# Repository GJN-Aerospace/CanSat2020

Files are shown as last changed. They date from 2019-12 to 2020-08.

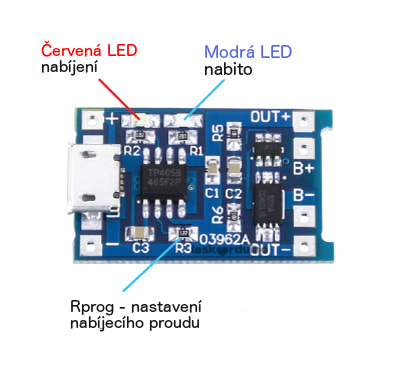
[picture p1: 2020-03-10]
Probe/Hardware/Components/Battery/Nabíječka Li-ion článku TP4056 s ochranou/LA120013-4.png

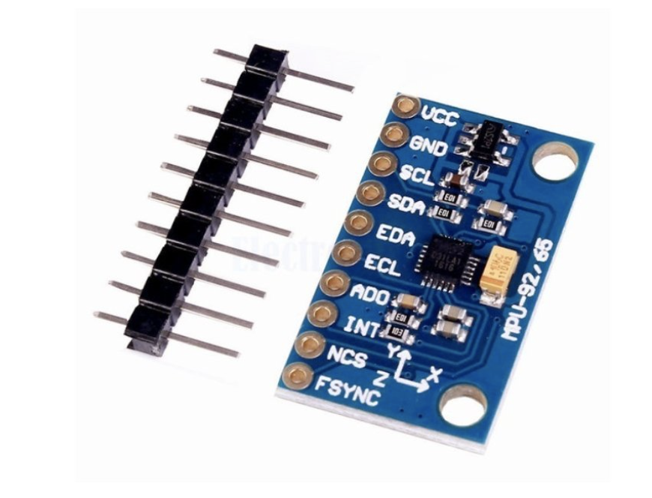
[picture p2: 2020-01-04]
Probe/Hardware/Components/MPU-9250/Screenshot 2020-01-01 at 14.21.48.png

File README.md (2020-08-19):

# CanSat 2020

<a href="https://github.com/GJN-Aerospace">GJN Aerospace Logo</a>

GitHub repository for CanSat 2020 competitoin. You can find here a design of **our CanSat probe PKII** but also our Arduino code for openCanSat kit. 

## Probe

We designed our own probe. It name is "Cosmic Song II" or for short just CSII (in czech Píseň kosmická II, PKII). But we have in Software section a code for our backup probe from openCanSat kit. 

## GroundStation

We use as a our Ground Station a baseStation from openCanSat kit. So you can find in Software folder our code for it. 

### Links

* [openCanSat](http://kit.sciencein.cz)

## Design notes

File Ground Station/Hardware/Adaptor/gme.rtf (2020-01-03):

https://www.gme.cz/redukce-sma-bnc-z-z-50r

Redukce z SMA zásuvka na BNC zásuvka. Impedance 50ohm. Materiál: niklovaná mosaz (NM), izolace: teflon

Kód produktu | 816-044
Váha | 0.00960 Kg
Redukce z: | SMA zásuvka -
Poznámka: | - -
Redukce na: | BNC zásuvka -
Tvar redukce: | Rovná -
Typ: | Redukce -
Výrobce: | - -

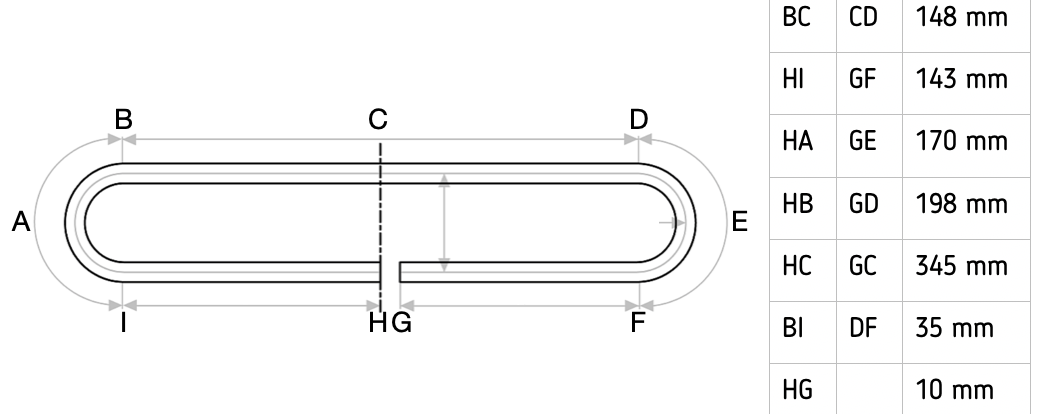
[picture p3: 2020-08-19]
Ground Station/Hardware/Antenna/Dipole.png

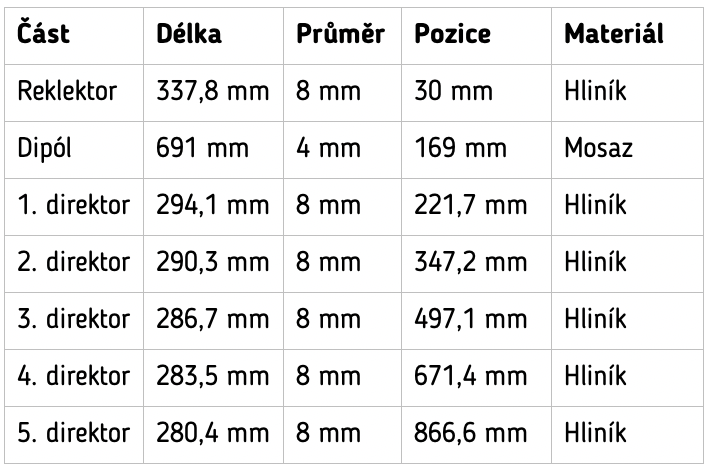
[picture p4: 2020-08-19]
Ground Station/Hardware/Antenna/Table.png

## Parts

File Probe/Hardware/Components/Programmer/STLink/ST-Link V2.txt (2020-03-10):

Detailní popis produktu

ST-Link V2 Programátor STM8 STM32

Mini programátor založený na výkonném mikroprocesoru STM32 od STMicroelectronics.

Specifikace:

STM32 32-bit ARM Cortex MCUs
Napájení i komunikace přes USB kabel.
Čtení, Zápis a Verifikace
ICSP výstup na kabel
2x LED, indikace napájení a komunikace
Součástí dodávky:

1ks ST-Link V2 Programátor STM8 STM32
1ks kabel

https://www.st.com/en/development-tools/stvp-stm32.html

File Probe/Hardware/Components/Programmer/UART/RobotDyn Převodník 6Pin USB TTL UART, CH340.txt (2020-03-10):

Detailní popis produktu

Převodník 6Pin USB TTL UART, RobotDyn. Bez nutnosti mačkat reset!

Převodník úrovní slouží ke komunikaci mezi PC a zařízením s UART. Využijete jej například pro programování Arduino bez USB portu.

POZOR, už několikrát jsme měli v ruce kus, který měl přehozené piny - Rx a Tx. Jestli Ti nejde nahrát kód, zkus přehodit tyhle dva piny.

Součástí dodávky:

1ks Převodník 6Pin USB TTL UART, RobotDyn

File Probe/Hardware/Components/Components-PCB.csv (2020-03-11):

Id | Designator | Package | Quantity | Designation | Supplier and ref
1 | G*** | gjna | 1 | LOGO
2 | G*** | pkiiB | 1 | LOGO
3 | G*** | pkii | 1 | LOGO
4 | J4 | Batt_PHS_Hor_Long18mm | 1 | Conn_01x03_Male
5 | U2 | HOPERF_RFM69HW | 1 | RFM69W
6 | J3 | microSD_HC_Wuerth_693072010801 | 1 | Micro_SD_Card
7 | J5,J6 | U.FL_Hirose_U.FL-R-SMT-1_Vertical | 2 | Conn_Coaxial
8 | J8 | PinHeader_1x03_P2.54mm_Vertical | 1 | Conn_01x03_Male
9 | J7 | PinHeader_1x06_P2.54mm_Vertical | 1 | Conn_01x06_Male
10 | C7,C4,C1,C5,C6 | C_0805_2012Metric | 5 | 100nF
11 | R1,R2 | R_0805_2012Metric | 2 | 10k
12 | D4 | D_DO-41_SOD81_P10.16mm_Horizontal | 1 | D
13 | C8,C10 | CP_Radial_D5.0mm_P2.00mm | 2 | 47uF
14 | C9 | C_0805_2012Metric | 1 | 10nF
15 | C2,C3 | C_0805_2012Metric | 2 | 15pF
16 | C11 | C_0805_2012Metric | 1 | 4.7uF
17 | D1,D2,D3 | LED_1206_3216Metric | 3 | LED
18 | IC1 | SON110P970X1010X230-18N | 1 | TESEO-LIV3F
19 | J1 | BME280 | 1 | BME280
20 | R3,R4,R5 | R_0805_2012Metric | 3 | R
21 | R6 | R_0805_2012Metric | 1 | 100k
22 | U1 | LQFP-64_10x10mm_P0.5mm | 1 | STM32F411RETx
23 | Y1 | Crystal_SMD_HC49-SD | 1 | Crystal
24 | J2 | MPU-9250-4pin | 1 | MPU-9250
25 | SW1 | Sw_ESP2010 | 1 | SW_DIP_x01
26 | U3 | SOT-23-5_HandSoldering | 1 | LD3985M33R_SOT23

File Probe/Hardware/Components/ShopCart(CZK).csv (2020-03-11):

Řádek č. | Objednací kód | Číslo dílu výrobce | Název výrobce | Výrobce / Popis | Součástka | Hodnota | Počet na DPS | Pouzdro | Dostupnost | Jednotková cena | Množství | Cena zakoupených položek | Cena použitých součástek | Poznámky | Odkaz
Line no. | Part No. | Manufacturer Part Number | Manufacturer Name | Manufacturer / Description | Part | Value | Qty. on PCB | Package | Availability | Unit Price (CZK) | Qty. | Line Price (CZK) | Price of used components | Notes | Link
1 | 2456967 | STM32F411RET6 | STMICROELECTRONICS | STMICROELECTRONICS ARM MCU, Režim Dávkového Sběru, STM32 Family STM32F4 Series Microcontrollers, ARM Cortex-M4, 32bitů | U1 |  | 1 | LQFP-64_10x10mm_P0.5mm | 1373 | 190,5460 | 2.0 | 381,09 | 190,55 |  | https://cz.farnell.com/stmicroelectronics/stm32f411ret6/mcu-32bit-cortex-m4-100mhz-lqfp/dp/2456967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
2 |  | RFM69W-433S2 | HOPE MICROELECTRONICS | HOPE MICROELECTRONICS RFM69W-433S2 | U2 |  | 1 | HOPERF_RFM69HW |  | 93,40 | 2,0 | 186,80 | 93,40 |  | https://www.tme.eu/cz/details/rfm69w-433s2/moduly-rf/hope-microelectronics/
3 | 2849790 | LDS3985M33R | STMICROELECTRONICS | STMICROELECTRONICS Pevný LDO Napěťový Regulátor, 2,5V až 6V, 150 mV pokles, 3,3V/300mA výstup, SOT-23-5 | U3 |  | 1 | SOT-23-5_HandSoldering | 3267 | 19,0290 | 4.0 | 76,12 | 19,03 |  | https://cz.farnell.com/stmicroelectronics/lds3985m33r/ldo-fixed-3-3v-0-3a-sot-23-5/dp/2849790?ost=2849790
4 | 3132401 | TESEO-LIV3R | STMICROELECTRONICS | STMICROELECTRONICS TINY ROM GNSS MODULE, LCC-18 | IC1 |  | 1 | SON110P970X1010X230-18N | 70 | 338,2060 | 2.0 | 676,41 | 338,21 |  | https://cz.farnell.com/stmicroelectronics/teseo-liv3r/tiny-rom-gnss-module-lcc-18/dp/3132401
5 | 9713794 | LFXTAL003151 | IQD FREQUENCY PRODUCTS | IQD FREQUENCY PRODUCTS Krystal, 8 MHz, HC49, 50 ppm, 16 pF, 30 ppm, Série HC-49/4HSMX | Y1 | 8 MHz | 1 | Crystal_SMD_HC49-SD | 3678 | 14,5090 | 3.0 | 43,53 | 14,51 |  | https://cz.farnell.com/iqd-frequency-products/lfxtal003151/crystal-smd-8mhz/dp/9713794
6 | 960-478 | S150BC-B4-1A |  | LED 1206 BLUE 120/120° S150BC-B4-1A (k ní rezistor 5.6 ohm) | D1, D3 |  | 2 | LED_1206_3216Metric |  | 1,50 | 6.0 | 9,00 | 3,00 |  | https://www.gme.cz/led-1206-blue-120-120
7 | 960-481 | S150W-W2-1B |  | LED 1206 COOL WHITE 350/120° S150W-W2-1B (k ní rezistor 27 ohm) | D2 |  | 1 | LED_1206_3216Metric |  | 2,70 | 6.0 | 16,20 | 2,70 |  | https://www.gme.cz/led-1206-cool-white-350-120
8 | 2335181 | 1N4004-E3/54 | VISHAY | VISHAY Dioda se Standard Charakterist Obnovení, 400 V, 1 A, Samostatná, 1.1 V, 30 A | D4 |  | 1 | D_DO-41_SOD81_P10.16mm_Horizontal | 32455 | 4,0330 | 5.0 | 20,17 | 4,03 |  | https://cz.farnell.com/vishay/1n4004-e3-54/rectifier-standard-1a-400v-do/dp/2335181
9 |  |  |  | Arduino Senzor tlaku, teploty a vlhkosti BME280 | J1 |  | 1 | BME280 |  | 233,00 | 1,0 | 233,00 | 233,00 |  | https://www.laskarduino.cz/arduino-senzor-tlaku--teploty-a-vlhkosti-bme280/
10 |  |  |  | Arduino 9DOF Gyroskop + Akcelerometr + Magnetometr MPU-9250 SPI/IIC | J2 |  | 1 | MPU-9250-4pin |  | 198,00 | 1,0 | 198,00 | 198,00 |  | https://www.laskarduino.cz/arduino-9dof-gyroskop-akcelerometr-magnetometr-mpu-9250-spi-iic/
11 | 832-271 | 112C-T B A R-R02 | ATTEN | SLOT-SDMICRO/1 | J3 |  | 1 | microSD_HC_Wuerth_693072010801 |  | 28,00 | 2.0 | 56,00 | 28,00 |  | https://www.gme.cz/slot-sdmicro-1
12 | 800-169 |  |  | Konektor se zámkem PSH02-03WG, Konektor se zámkem do DPS 3 kontaktů, rozteč 2,54mm | J4 |  | 1 | Batt_PHS_Hor_Long18mm |  | 4,40 | 2,0 | 8,80 | 4,40 |  | https://www.gme.cz/konektor-se-zamkem-psh02-03wg
13 | 1688077 | U.FL-R-SMT-1(10) | HIROSE(HRS) | HIROSE(HRS) RF / Koaxiální Konektor, UFL Koaxiální, Přímý Jack, Povrchová Montáž Vertikální, 50 ohm, Mosaz | J5, J6 |  | 2 | U.FL_Hirose_U.FL-R-SMT-1_Vertical | 158442 | 22,6280 | 10.0 | 226,28 | 45,26 |  | https://cz.farnell.com/hirose-hrs/u-fl-r-smt-1-10/rf-coaxial-u-fl-straight-jack/dp/1688077
14 |  |  |  | Dupont 40Pin 2,54 mm pinový pás, LA217003BK (potřeba rozdělit) | J7, J8 |  | 1 | PinHeader_1x03_P2.54mm_Vertical, PinHeader_1x06_P2.54mm_Vertical |  | 4,00 | 1,0 | 4,00 | 4,00 |  | https://www.laskarduino.cz/dupont-40pin-2-54-mm-pinovy-pas/
15 | 2332715 | 08051C104JAT2A | AVX | AVX SMD Vícevrstvý Keramický Kondenzátor, 0.1 µF, 100 V, 0805 [2012 Metrické], ± 5%, X7R, AVX 0805 MLCC | C1, C4, C5, C6, C7 | 100 nF | 5 | C_0805_2012Metric | 109512 | 7,4120 | 20.0 | 148,24 | 37,06 |  | https://cz.farnell.com/avx/08051c104jat2a/cap-0-1-f-100v-5-x7r-0805/dp/2332715?st=0805%20kondenzátor
16 | 1658873 | 08051A150JAT2A | AVX | AVX SMD Vícevrstvý Keramický Kondenzátor, 15 pF, 100 V, 0805 [2012 Metrické], ± 5%, C0G / NP0 | C2, C3 | 15 pF | 2 | C_0805_2012Metric | 22234 | 4,3480 | 10.0 | 43,48 | 8,70 |  | https://cz.farnell.com/avx/08051a150jat2a/cap-15pf-100v-5-c0g-np0-0805/dp/1658873
17 | 1144612 | 16YXF47MEFC5X11 | RUBYCON | RUBYCON Elektrolytický Kondenzátor, Miniaturní, 47 µF, 16 V, Série YXF, ± 20%, Radiální Vývodové, 5 mm | C8, C10 | 47 uF | 2 | CP_Radial_D5.0mm_P2.00mm | 5204 | 5,1860 | 5.0 | 25,93 | 10,37 |  | https://cz.farnell.com/rubycon/16yxf47mefc5x11/cap-47-f-16v-20/dp/1144612
18 | 1833850 | 08051C103K4Z2A | AVX | AVX SMD Vícevrstvý Keramický Kondenzátor, 10000 pF, 100 V, 0805 [2012 Metrické], ± 10%, X7R, Série MLCC | C9 | 10 nF | 1 | C_0805_2012Metric | 2700 | 5.9190 | 10.0 | 59.19 | 5,92 |  | https://cz.farnell.com/avx/08051c103k4z2a/cap-0-01-f-100v-10-x7r-0805/dp/1833850
19 | 905-160 | CC0805KKX5R6BB475 | YAGEO | Keramický kondenzátor CKS0805 4,7u/10V X5R 10% YAGEO | C11 | 4.7 uF | 1 | C_0805_2012Metric |  | 4,50 | 5,0 | 22,50 | 4,50 |  | https://www.gme.cz/cks0805-4-7u-10v-x5r-10-yageo
20 | 901-176 | RC0805FR-0710KL | YAGEO | SMD Rezistor R0805 10k 1% YAGEO | R1, R2 | 10 kohm | 2 | R_0805_2012Metric |  | 3,30 | 8,0 | 26,40 | 6,60 |  | https://www.gme.cz/r0805-10k-1-yageo
21 | 2138778 | CRCW080527R0FKEA. | VISHAY | VISHAY SMD Čipový Rezistor, Tlustý Film, 0805 [2012 Metrické], 27 ohm, Série CRCW, 150 V, Thick Film | R4 | 27 ohm | 1 | R_0805_2012Metric | 24485 | 2,0640 | 10.0 | 20,64 | 2,06 |  | https://cz.farnell.com/vishay/crcw080527r0fkea/res-27r-1-0-125w-0805-thick-film/dp/2138778
22 | 2073600 | MCMR08W5R60FTL | MULTICOMP PRO | MULTICOMP PRO SMD Čipový Rezistor, Keramický, 0805 [2012 Metrické], 5.6 ohm, Série MCMR, 150 V, Thick Film | R3, R5 | 5.6 ohm | 2 | R_0805_2012Metric | 2013 | 0,6390 | 10.0 | 6,39 | 1,28 |  | https://cz.farnell.com/multicomp/mcmr08w5r60ftl/res-5r6-1-0-125w-0805-ceramic/dp/2073600
23 | 1469860 | CRCW0805100KFKEA | VISHAY | VISHAY SMD Čipový Rezistor, Tlustý Film, 0805 [2012 Metrické], 100 kohm, Série CRCW, 150 V, Thick Film | R6 | 100 kohm | 1 | R_0805_2012Metric | 85066 | 2,1000 | 10.0 | 21,00 | 2,10 |  | https://cz.farnell.com/vishay/crcw0805100kfkea/res-100k-1-0-125w-0805-thick-film/dp/1469860
24 |  |  |  | ECE ESP2010, Přepínač: posuvný; Polohy: 2; SPDT; 0,5A/12VDC; ON-ON | SW1 |  | 1 | Sw_ESP2010 (1x03_P2.54mm) |  | 18,67 | 2,0 | 37,34 | 18,67 |  | https://www.tme.eu/cz/details/esp2010/posuvne-prepinace/ece/
25 | 2433469 | NUCLEO-F411RE | STMICROELECTRONICS | STMICROELECTRONICS Vývojová Deska, STM32 Nucleo-64, STM32F411RE MCU, Arduino Uno & Morpho Připojení |  |  |  |  | 373 | 327,1630 | 1.0 | 327,16 | 0,00 |  | https://cz.farnell.com/stmicroelectronics/nucleo-f411re/dev-board-cortex-m4-mcu/dp/2433469
26 |  |  |  | EHAO LiPol Baterie 603443 900mAh 3.7V, LA123014 |  |  | 1 |  |  | 158,00 | 1,0 | 158,00 | 158,00 |  | https://www.laskarduino.cz/baterie-li-po-3-7v-900mah-lipo/
27 | 800-085 | A2543-H03 |  | Konektor se zámkem PFH02-03P |  |  | 1 |  |  | 0,70 | 1,0 | 0,70 | 0,70 |  | https://www.gme.cz/product/4962
28 | 800-191 |  |  | Kontakt PFF02-01FG TAPE |  |  | 3 |  |  | 2,20 | 3,0 | 6,60 | 6,60 |  | https://www.gme.cz/kontakt-pff02-01fg-tape
28 |  |  |  | Nabíječka Li-ion článku TP4056 s ochranou microUSB, LA123003C |  |  | 1 |  |  | 25,00 | 1,0 | 25,00 | 25,00 |  | https://www.laskarduino.cz/nabijecka-li-ion-clanku-tp4056-s-ochranou-microusb/
29 | 2401856 | 103456A-1S-3M | BAK | BAK Dobíjecí Baterie, 3.7 V, Lithium Ion, 2.05 Ah, Konektor |  |  |  |  | 3441 | 551,8630 | 1.0 | 551,86 | 0,00 |  | https://cz.farnell.com/bak/103456a-1s-3m/battery-lithium-ion-3-7v-2050mah/dp/2401856
30 | 2913959 | 146168-0001 | MOLEX | MOLEX Anténa, GPS, 1,578 GHz až 1,572 GHz, 5,5 dBi Zisk, SMD, Pravostranná Kruhová |  |  | 1 |  | 1570 | 45,9670 | 2.0 | 91,93 | 45,97 |  | https://cz.farnell.com/molex/146168-0001/gps-antenna-rhc-1-572-1-578ghz/dp/2913959?st=ant%C3%A9na%20gps
31 | 2096159 | 66089-0406 | ANAREN | ANAREN Anténa, Prutová, Přímý RF, U.Fl, 433MHz |  |  | 1 |  | 227 | 163,4260 | 1.0 | 163,43 | 163,43 |  | https://cz.farnell.com/anaren/66089-0406/antenna-66089-04c-433mhz-u-fl/dp/2096159
32 | 661-057 | 120306Z33-10 |  | Fotocuprextit 160x100x1,5mm, dvouvrstvý, FR4 BEP100160A2 |  |  |  |  |  | 96,00 | 1,0 | 96,00 | 0,00 |  | https://www.gme.cz/fotocuprextit-fr4-160x100x1-5-dvouvrstvy
33 |  |  |  | RobotDyn Převodník 6Pin USB TTL UART, CH340, LA161003 |  |  |  |  |  | 48,00 | 1,0 | 48,00 | 0,00 |  | https://www.laskarduino.cz/robotdyn-prevodnik-6pin-usb-ttl-uart--ch340/
34 |  |  | JLCPCB | PCB Prototype, 56mm*56mm, FR4-Standard Tg 130-140C, HASL(with lead), Thickness 1.6 mm, Black, |  |  | 1 |  |  | 11,34 | 10,0 | 113,41 | 11,34 |  | https://jlcpcb.com
 |  |  | Dílčí součet/Total per component (CZK) | 2631,829
 |  |  | Celkem/Total (CZK) | 4069,41
 |  |  | Cena kompletního DPS/Total for complete PCB (CZK) | 1686,37

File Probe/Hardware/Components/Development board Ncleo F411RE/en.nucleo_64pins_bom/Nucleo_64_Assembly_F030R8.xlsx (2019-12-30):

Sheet: BOM Report
Bill of Materials
Source Data From:
Project:
Variant: |  | None
Creation Date: | 8/1/2013 | 13:33:45
Print Date: | 2014-10-10 | 15:19:39
MB1136C-03 BOM & components order and assembly
Select MCU Reference in follow list: |  |  | Select Socket option:
F030R8 |  |  | without socket
Board name:NUCLEO-F030R8
Comment | Designator | Footprint | Quantity | Assembly | Ordered by | Comments | Description | Manufacturer 1 | Part#1 | Manufacturer 2 | Part#2 | ECCN US | ECCN EU | Info source
USER (Blue) | B1 | PB10 | 1 | Blue | Subcon | Blue | touch switch,Blue,6*6,SMT,TD-0341X-GO0,wealthmetal | wealthmetal | TD0341X-G01-BLU |  |  | NA | NA
TD-0341 [RESET/Black] | B2 | PB10 | 1 | Black | Subcon | Black | touch switch,Black,6*6,SMT,TD-0341X-A00,wealthmetal | wealthmetal | TD0341X-G01-BLA |  |  | NA | NA
100nF | C1, C4, C5, C6, C7, C11, C12, C14, C15, C19, C20, C23, C24, C27, C28, C30 | 0603C | 16 |  | Subcon |  | Capacitor,100nF,10%,50V,X7R,0603,YAGEO; | YAGEO | CC0603KRX7R9BB104 |  |  | NA | NA
1uF_X5R_0603 | C2, C13, C18, C21, C29 | 0603C | 5 |  | Subcon |  | Capacitor,1uF,0603,16V,10%,X5R,YAGEO | YAGEO | CC0603KRX5R7BB105 |  |  | NA | NA
20pF | C3, C8 | 0603C | 2 |  | Subcon |  | Capacitor,20pF,5%,50V,NPO,0603,YAGEO | YAGEO | CC0603JRNPO9BN200 |  |  | NA | NA
20pF[N/A] | C10 | 0603C | 1 | [N/A] | Subcon |  | Capacitor,20pF,5%,50V,NPO,0603,YAGEO | YAGEO | CC0603JRNPO9BN200 |  |  | NA | NA
10nF_X7R_0603 | C9 | 0603C | 1 |  | Subcon |  | Capacitor,10nF,0603,50V,10%,X7R,YAGEO; | YAGEO | CC0603KRX7R9BB103 |  |  | NA | NA
10uF(25V) | C16 | TAN-B | 1 |  | Subcon |  | Tan Capacitor,10uF,10%,25V,B,AVX | AVX | TAJB106K025R |  |  | NA | NA
10uF | C17 | TAN-A | 1 |  | Subcon |  | Tan Capacitor,10uF,10%,16V,A,AVX | AVX | TAJA106K016R |  |  | NA | NA
[N/A] | C22, C25 | TAN-A | 2 | [N/A] | Subcon |  | Capacitor,2.2uF,10%,16V,X7R,1206 | YAGEO | CC1206KKX7R7BB225 |  |  | NA | NA
4.7uF[N/A] | C26 | TAN-A | 1 | [N/A] | Subcon |  | Capacitor,4.7uF,10%,25V,X7R,1206 | YAGEO | CC1206KKX7R8BB475 |  |  | NA | NA
4.3pF | C31, C32 | 0603C | 2 |  | Subcon |  | Capacitor,4.3pF,±0.25pF,50V,COG,0603, | FENGHUA | 0603CG4R3C500NT | Murata | GRM1885C1H4R3CA01D | NA | NA
20pF[N/A] | C33, C34 | 0603C | 2 | [N/A] | Subcon |  | Capacitor,20pF,5%,50V,NPO,0603,YAGEO | YAGEO | CC0603JRNPO9BN200 |  |  | NA | NA
5075BMR-05-SM | CN1 | USB-MINI-B-SMD | 1 |  | Subcon | USB Mini Connector | USB,MUSB5QS-BM1H6-NLB-E,Townes | Townes | MUSB5QS-BM1H6-NLB-E | Neltron | 5075BMR-05-SM | NA | NA
Header 4 | CN2 | 1*4 | 1 |  | Subcon |  | Pin header male,2.54mm,1*4,L=11.6,180,1U,DIP,Lyconn | Lyconn | 313140S111116 |  |  | NA | NA
 | CN3, JP1, JP6 | SIP2/2.54 | 3 |  | Subcon |  | Pin header male,2.54mm,1*2,L=11.6,180,1U,DIP,Lyconn | Lyconn | 313140S111116 |  |  | NA | NA
[N/A] | JP4 | SIP2/2.54 | 1 | [N/A] | Subcon |  |  |  |  |  |  | NA | NA
313140S161185 | CN11, CN12 | SIP2/2.54 | 2x1/20 |  | Subcon | CN11,CN12 long headers on bottom layer same as CN7 & CN10 | Pin header male,2.54mm, 1*2P,L=6+2.5+10=18.5 313140S161185 | Lyconn | 313140S161185 |  |  | NA | NA
Header 6X1 | CN4 | 1*6P | 1 |  | Subcon |  | Header Female,1*6,2.54*8.5,Y type,1u,PAT,2.5MM | Lyconn | 218106S1610 |  |  | NA | NA
Header 10X1_Female | CN5 | 1*10P_FEMALE | 1 |  | Subcon |  | Header Female,1*10,2.54*8.5,Y,1u,PAT,2.5MM | Lyconn | 218110S1610 |  |  | NA | NA
Header 8X1_Female | CN6, CN9 | 1*8P_FEMALE | 2 |  | Subcon |  | Header Female,1*8,2.54*8.5,Y,1u,PAT2.5MM | Lyconn | 218108S1610 |  |  | NA | NA
Header 19X2 (313238S161185) | CN7, CN10 | 2*19P | 2 |  | Subcon | long headers on bottom layer | Pin header male,2.54mm, 2*19P,L=6+2.5+10=18.5 313238S161185 | Lyconn | 313238S161185 |  |  | NA | NA
Header 6X1_Female | CN8 | 1*6P_FEMALE | 1 |  | Subcon |  | Header Female,1*6,2.54*8.5,Y,1u,PAT,2.5MM | Lyconn | 218106S1610 |  |  | NA | NA
BAT60JFILM | D1, D2, D3 | SOD323/A | 3 |  | STM |  | Diode,BAT60JFILM,SOD323/A,ST,(X3 Code 9151097) | ST | BAT60JFILM |  |  | NA | NA
STPS2L30A | D4 | SMA | 1 |  | STM |  | Diode,STPS2L30A,DO214AC(SMA),ST,(X3 Code 9151083) | ST | STPS2L30A |  |  | NA | NA
 | JP5 | SIP3 | 1 |  | Subcon |  | Pin header male,2.54mm,1*3,L=11.6,180,1U,DIP,Lyconn | Lyconn | 313140S111116 |  |  | NA | NA
BEAD | L1 | 0603L | 1 |  | Subcon |  | Bead,600R,350mA,0603,FCM1608KF-601T05,Tai-tech | Tai-tech | FCM1608KF-601T05 |  |  | NA | NA
LD_BICOLOR_CMS | LD1 | HSMF-A201 | 1 |  | Subcon |  | LED,Bi-color,red-green,3.2 mm x 2.8 mm,LE-RGW35280,SMT, | everluck-led | LE-RGW35280 | Avago | HSMF-A201-A00J1 | EAR99 | NEC | Sub Co
Green | LD2 | 0603D | 1 |  | Subcon |  | LED,Green,0603 | Everlight | 19-213SY6C/S530-E2/TR8LED |  |  | EAR99 | NEC | Sub Co
RED | LD3 | 0603D | 1 |  | Subcon |  | LED,Red,0603 | Everlight | 19-213-R6C-AP1Q2B-3T |  |  | EAR99 | NEC | Sub Co
10K | R1, R3, R12, R33 | 0603R | 4 |  | Subcon |  | Resistor,10K,0603,5%,YAGEO | YAGEO | RC0603JR-0710KL |  |  | NA | NA
4K7 | R4, R23, R27, R28, R30 | 0603R | 5 |  | Subcon |  | Resistor,4.7K,0603,1% | YAGEO | RC0603FR-074K7L |  |  | NA | NA
22 | R5, R8, R13, R22 | 0603R | 4 |  | Subcon |  | Resistor,22R,0603,1% | YAGEO | RC0603FR-0722RL |  |  | NA | NA
100K | R6, R14, R15 | 0603R | 3 |  | Subcon |  | Resistor,100K,0603,1% | YAGEO | RC0603FR-07100KL |  |  | NA | NA
2K7 | R7 | 0603R | 1 |  | Subcon |  | Resistor,2.7K,0603,1%,YAGEO | YAGEO | RC0603FR-072K7L |  |  | NA | NA
100 | R11, R20, R21, R24, R25, R29 | 0603R | 6 |  | Subcon |  | Resistor,100R,0603,1% | YAGEO | RC0603FR-07100RL |  |  | NA | NA
36K | R10 | 0603R | 1 |  | Subcon |  | Resistor,36K,0603,1% | YAGEO | RC0603FR-0736KL |  |  | NA | NA
1K5 | R16 | 0603R | 1 |  | Subcon |  | Resistor,1.5K,0603,1%,YAGEO | YAGEO | RC0603FR-071K5L |  |  | NA | NA
0 | R17, R18, R19, R34, R36 | 0603R | 5 |  | Subcon |  | Resistor,0R,0603,5%,YAGEO | YAGEO | RC0603JR-070RL |  |  | NA | NA
510 | R31 | 0603R | 1 |  | Subcon |  | Resistor,510R,0603,1% | YAGEO | RC0603FR-07510RL |  |  | NA | NA
1K | R32 | 0603R | 1 |  | Subcon |  | Resistor,1K,0603,1%,YAGEO | YAGEO | RC0603FR-071KL |  |  | NA | NA
[N/A] | R2, R9, R26, R35, R37 | 0603R | 5 | [N/A] | Subcon |  |  |  |  |  |  | NA | NA
Circuit Breaker | SB2, SB3, SB5, SB7, SB9, SB12, SB13, SB14, SB15, SB16, SB17, SB21, SB45, SB50, SB51, SB54, SB56, SB57, SB60 | JP2_SMD | 19 |  | Subcon | Dafult Closed | Resistor,0R,0603,5%,YAGEO | YAGEO | RC0603JR-070RL |  |  | NA | NA
[N/A] | SB1, SB4, SB6, SB8, SB10, SB11, SB46, SB48, SB49, SB52, SB55, SB63 | JP2_SMD | 12 | [N/A] | Subcon | Dafult Open |  |  |  |  |  | NA | NA
Circuit Breaker | SB19, SB23, SB25, SB27, SB28, SB30, SB32, SB35, SB37, SB38, SB40, SB41, SB42, SB47, SB58, SB64 | JP2_SMD | 16 |  | Subcon | Solder Bridges(Closed) | Resistor,0R,0603,5%,YAGEO | YAGEO | RC0603JR-070RL |  |  | NA | NA
[N/A] | SB18, SB20, SB22, SB24, SB26, SB29, SB31, SB33, SB34, SB36, SB39, SB43, SB44, SB53, SB59, SB61, SB62, SB65 | JP2_SMD | 18 | [N/A] | Subcon | Solder Bridges(Open) |  |  |  |  |  | NA | NA
9013 | T1 | SOT-23 | 1 |  | Subcon |  | Transistor,MMBT9013L/G,SOT-23,unisonic | unisonic | MMBT9013L/G |  |  | EAR99 | NEC | Sub Co
STS7PF30L | T2 | SO8 | 1 |  | STM |  | MOS Transistor,STS7PF30L,SO-8,ST | ST | STS7PF30L |  |  | EAR99 | NEC | http://tcdr.sgp.st.com:23000/tcdr/app?page=tcdr/productList
LD3985M33R | U1 | SOT-23-5L | 1 |  | STM |  | IC,3.3V,LD3985M33R,SOT23-5L,ST,(X3 Code 9176161) | ST | LD3985M33R |  |  | EAR99 | NEC | http://tcdr.sgp.st.com:23000/tcdr/app?page=tcdr/productList
STM32F103CBT6 | U2 | QFP48 7X7 | 1 |  | STM |  | IC,STM32F103CBT6 (128K),LQFP-48,(9175111) | ST | STM32F103CBT6 |  |  | 3A991A2 | NEC | http://tcdr.sgp.st.com:23000/tcdr/app?page=tcdr/productList
LD1117S50TR | U3 | SOT-223 | 1 |  | STM |  | IC,LD1117S50TR,SOT223,ST | ST | LD1117S50TR |  |  | EAR99 | NEC | http://tcdr.sgp.st.com:23000/tcdr/app?page=tcdr/productList
LD39050PU33R | U4 | DFN6(3X3) | 1 |  | STM |  | IC,LD39050PU33R,SMT | ST | LD39050PU33R |  |  | EAR99 | NEC | http://tcdr.sgp.st.com:23000/tcdr/app?page=tcdr/productList
STM32F030R8T6 | U5 | LQFP64 | 1 | without socket | STM |  | IC,STM32L053R8T6,LQFP64,SMT | ST | STM32L053R8T6 |  |  | 3A991A2 | NEC | http://tcdr.sgp.st.com:23000/tcdr/app?page=tcdr/productList
8MHz(12pF) | X1 | XTAL1 | 1 |  | Subcon |  | crystal,9SL8000012AFXHF0-SJ28,12PF,8M,20PPM | HongKongCrystal | 9SL8000012AFXHF0-SJ28 |  |  | EAR99 | NEC | Sub Co
ABS25-32.768KHZ-6-T | X2 | XTAL_4SM_8X3R8 | 1 |  | Subcon |  | Crystal 32.768KHz ±20ppm (Tol) 6pF -40+85C Low Profile ESR 50kOhm 4-Pin SMD T/R | Abracon | ABS25-32.768KHZ-6-T |  |  | NA | NA
8MHz(16pF)[N/A] | X3 | XTAL1 | 1 | [N/A] | Subcon |  |  |  |  |  |  | NA | NA
Stick for Board name |  |  | 1 | Board name:NUCLEO-F030R8 | Subcon |  |  |  |  |  |  | NA | NA
blister |  |  | 1 |  | Subcon |  |  |  |  |  |  | NA | NA
IC149-064-075-B5 | MCU socket |  | 1 | [N/A] | Subcon |  | IC Socket,IC149-064-075-B5 | Yamaichi | IC149-064-075-B5 |  |  | NA | NA

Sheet: Assembly req.
Bill of Materials
Source Data From:
Project:
Variant: |  | None
Creation Date: | 08/27/2012 | 13:33:45
Print Date: | 2014-10-10 | 15:19:39
MB1136C-03 Assembly Requirement
Comment | Designator | Footprint | Quantity | Assembly | Ordered by | Comments
 | JP1 | SIP2/2.54 | 1 | open | Subcon | PWR_EXT not connected to 3.3V STLINK
 | JP5 | SIP3 | 1 | 1<->2 | Subcon | 5V power selection to U5V
 | JP6 | SIP2/2.54 | 1 | close | Subcon | Idd measurment disable
 | CN11 | SIP2/2.54 | 1 | close on top side | Subcon | GOUND PINS
 | CN12 | SIP2/2.54 | 1 | close on top side | Subcon | GOUND PINS

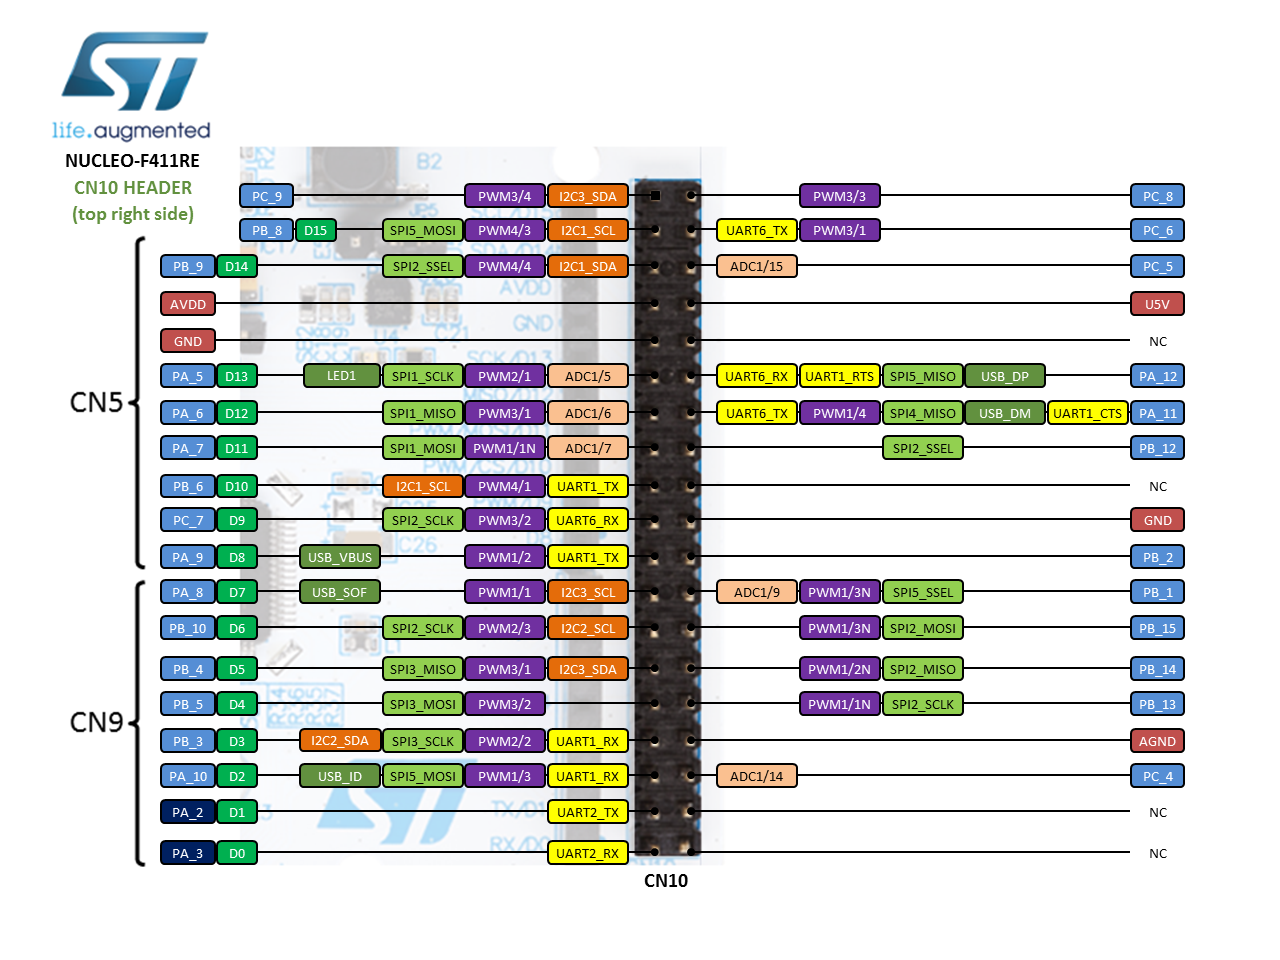
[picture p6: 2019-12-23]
Probe/Hardware/Components/Development board Ncleo F411RE/mbed.com/nucleo_f411re_2017_11_14_mor_right.png

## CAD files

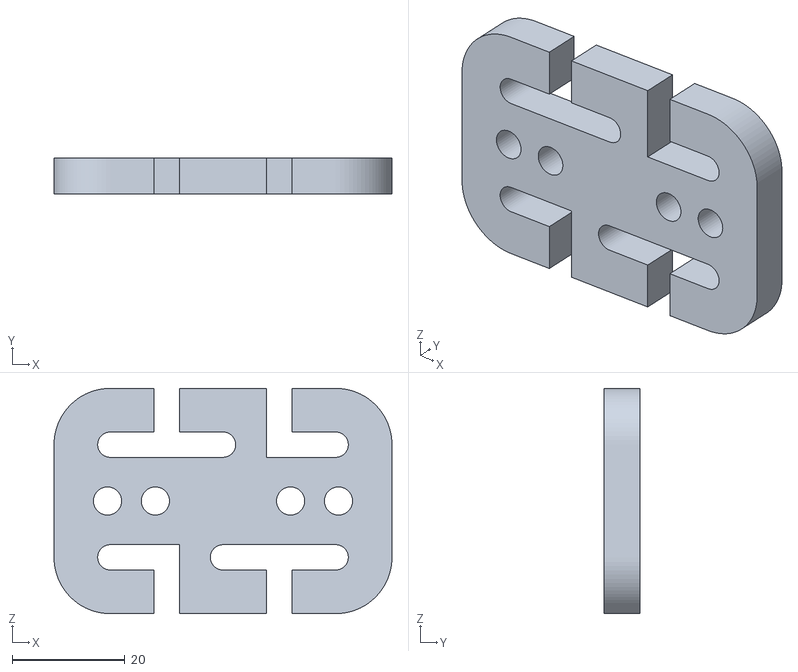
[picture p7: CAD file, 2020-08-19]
Parachute/SliderV2(CPE).stl
60.0 x 6.45 x 40.0

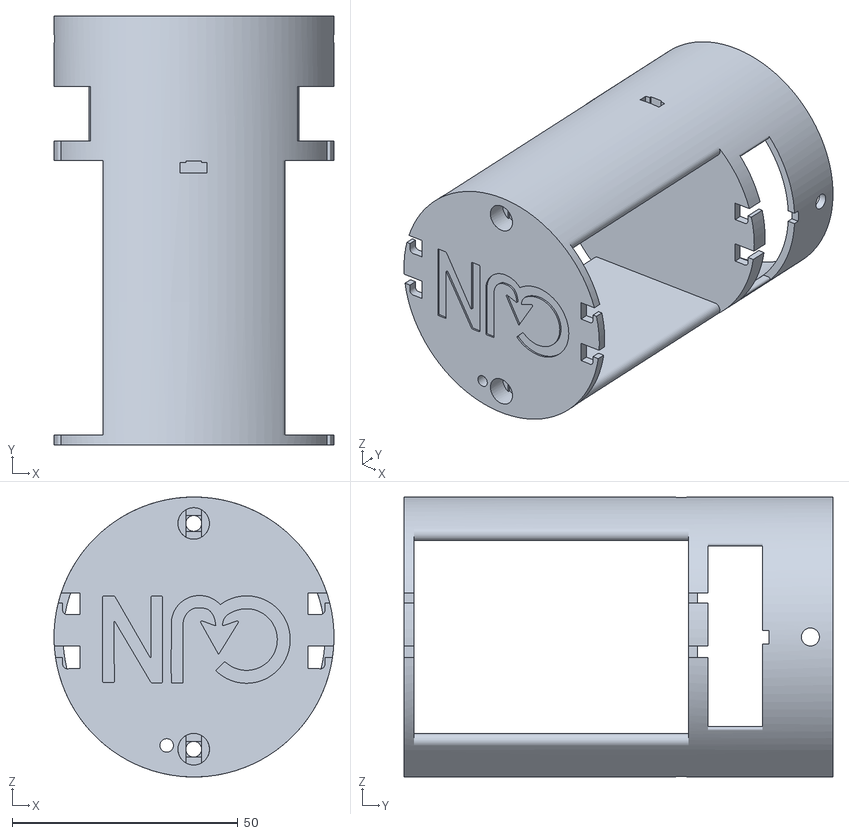
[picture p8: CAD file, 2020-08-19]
Probe/Hardware/Case/PouzdroPKII(CPE).stl
62.0 x 95.0 x 62.0

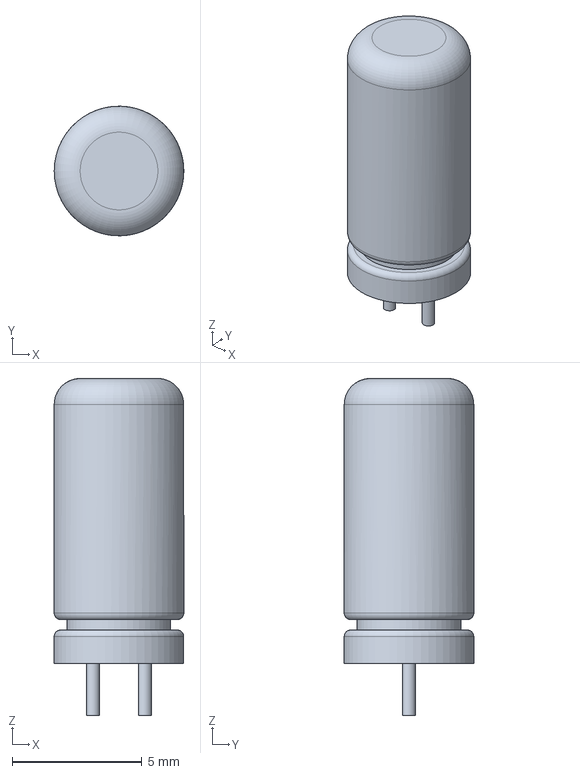
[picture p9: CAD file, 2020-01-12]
Probe/Hardware/Components/Capacitors/C47uF v3.step
5.00 x 5.00 x 13.0 mm

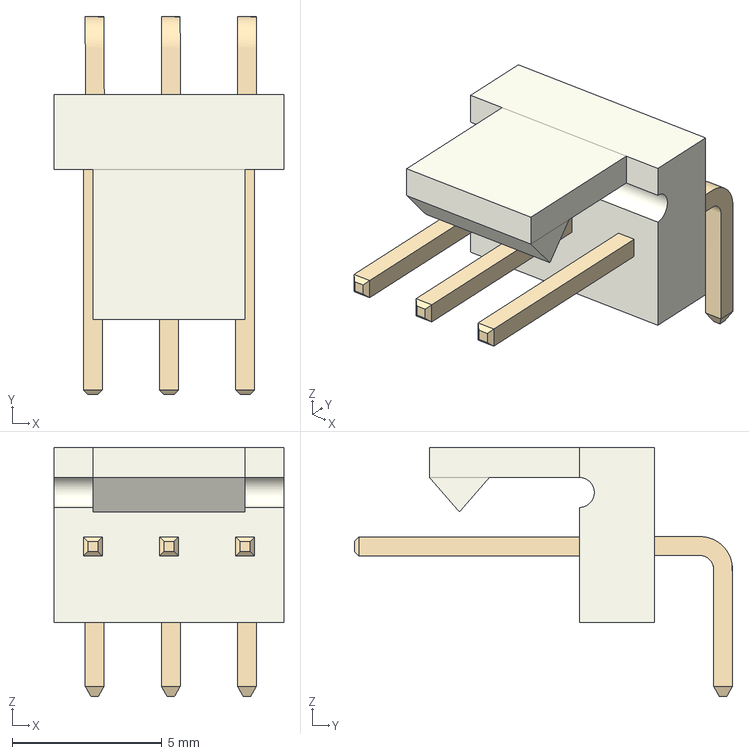
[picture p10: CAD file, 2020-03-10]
Probe/Hardware/Components/Connectors/Battery Connectors/ PSH02-03WG/BattConn.step
7.66 x 12.6 x 8.31 mm

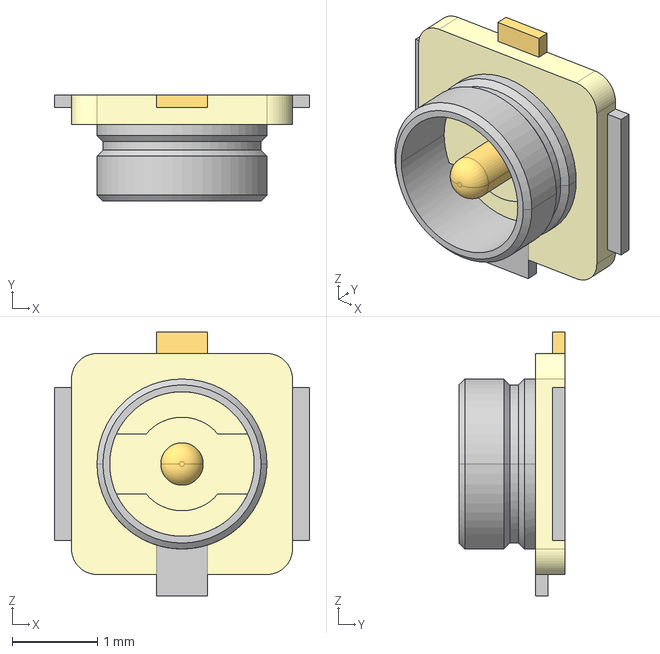
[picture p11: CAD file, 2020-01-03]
Probe/Hardware/Components/Connectors/U.FL/WRF-1600355_0001223058S/U.FL-R-SMT-1.stp
3.00 x 1.25 x 3.10 mm

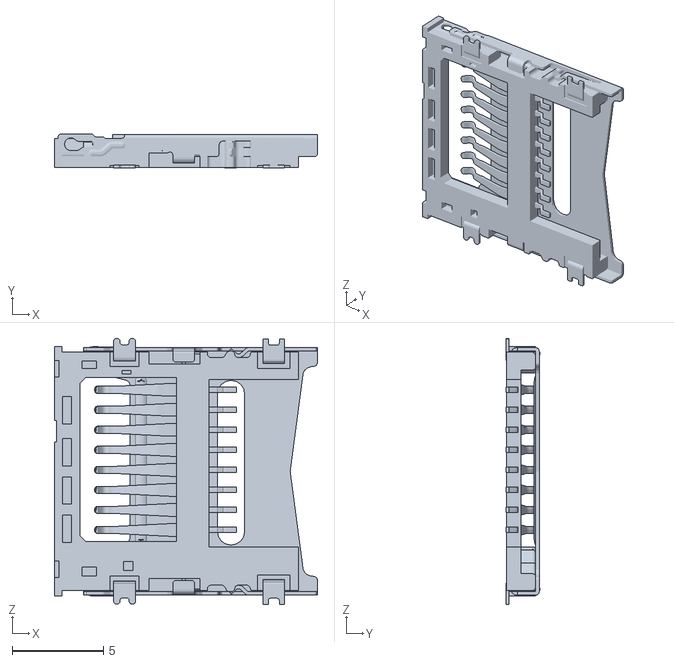
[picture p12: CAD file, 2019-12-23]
Probe/Hardware/Components/MicroSD Slot/GCT/3D/MEM2067-02-180-00-A.obj
14.4 x 1.86 x 14.6

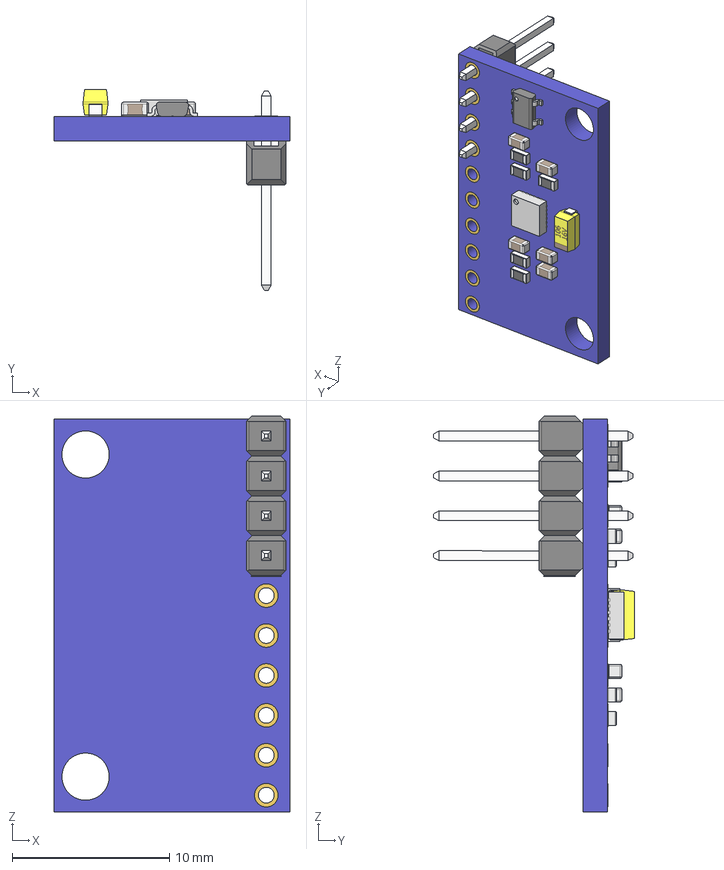
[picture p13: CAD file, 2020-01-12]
Probe/Hardware/Components/MPU-9250/MPU-9250.step
15.0 x 12.8 x 25.2 mm
board
hole_plating x 20
Pin Header 1x10 TH Pitch 2
QFN-24 3x3 0
tantalum 10uF
SOT23_5
RESC-0603 x 5
CAPC-0603-T0 x 5

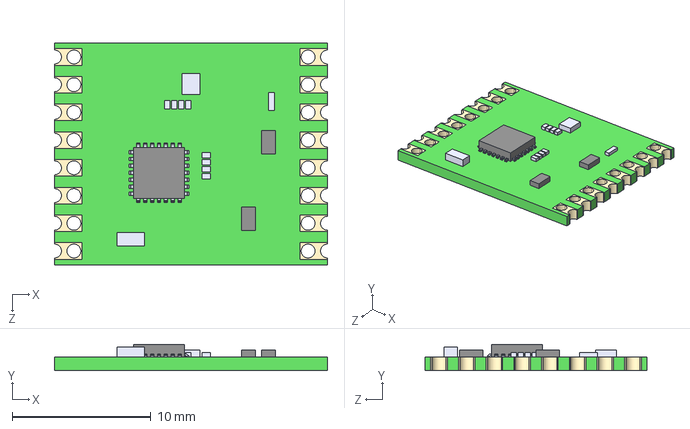
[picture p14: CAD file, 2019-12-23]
Probe/Hardware/Components/RFM69W/RFM69HW-868S2--3DModel-STEP-1.STEP
19.7 x 1.90 x 16.0 mm

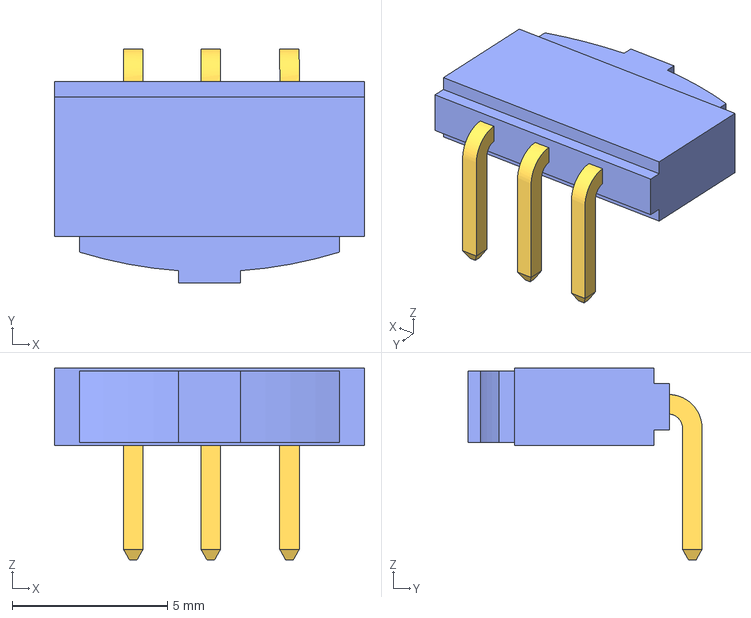
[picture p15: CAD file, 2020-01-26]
Probe/Hardware/Components/Switch/ESP2010.step
10.0 x 7.55 x 6.19 mm

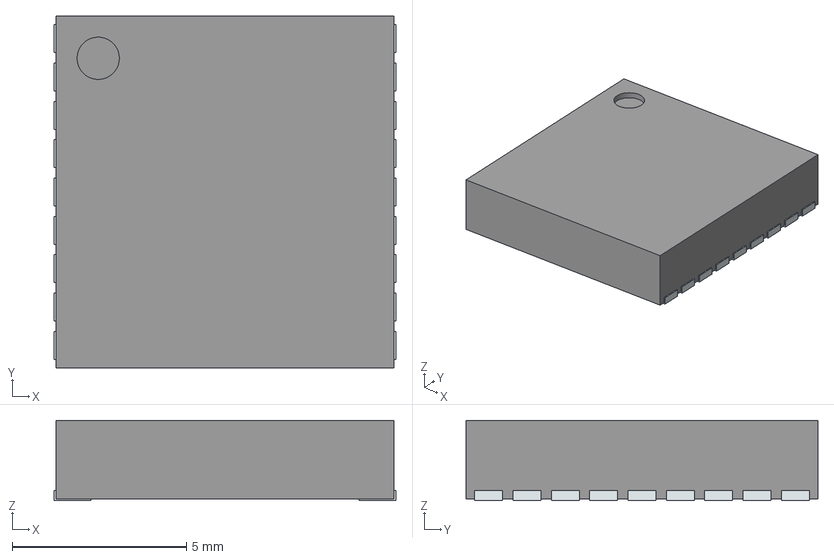
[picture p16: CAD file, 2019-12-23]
Probe/Hardware/Components/TESEO LIV3R/TESEO-LIV3F.stp
9.80 x 10.1 x 2.30 mm
PinsArrayLR

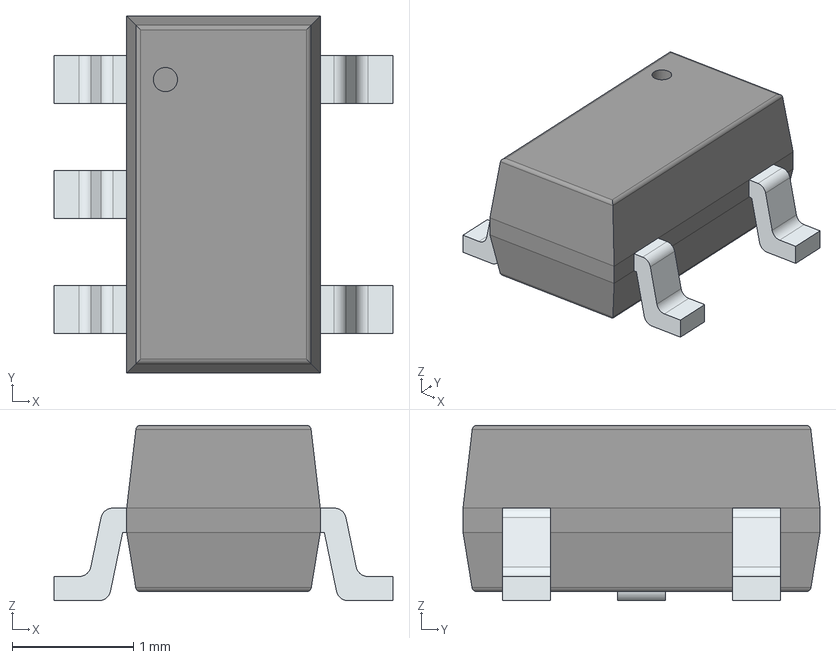
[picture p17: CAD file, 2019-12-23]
Probe/Hardware/Components/Voltage Regulator/LIB_LD3985M33R/LD3985M33R/3D/LD3985M33R.stp
2.80 x 2.95 x 1.45 mm
PinsArrayL
PinsArrayR

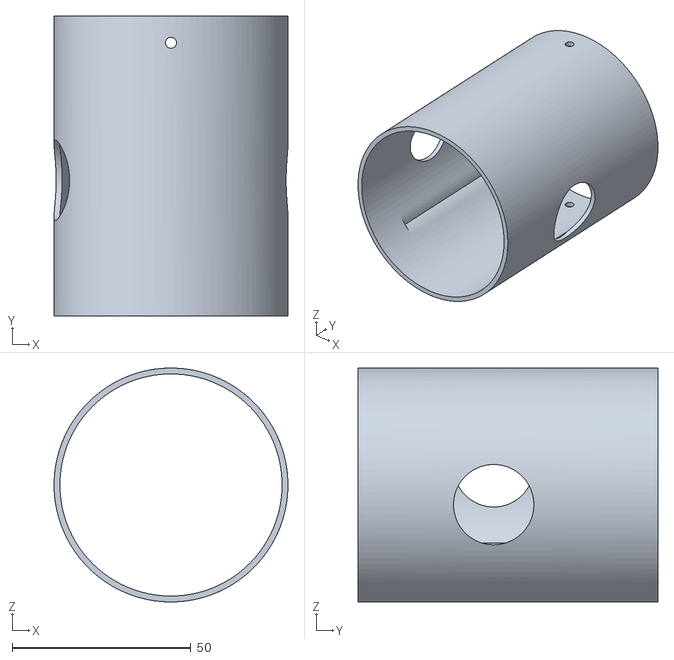
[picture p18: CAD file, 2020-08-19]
Probe/openCanSat PKII/PlastOCS(Flex).stl
65.5 x 84.0 x 65.5

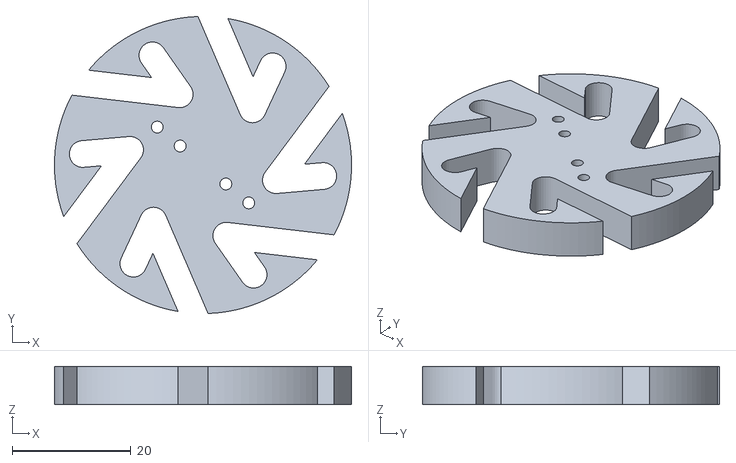
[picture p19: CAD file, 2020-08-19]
Parachute/SliderO(2x, CPE).stl
50.0 x 50.0 x 6.45

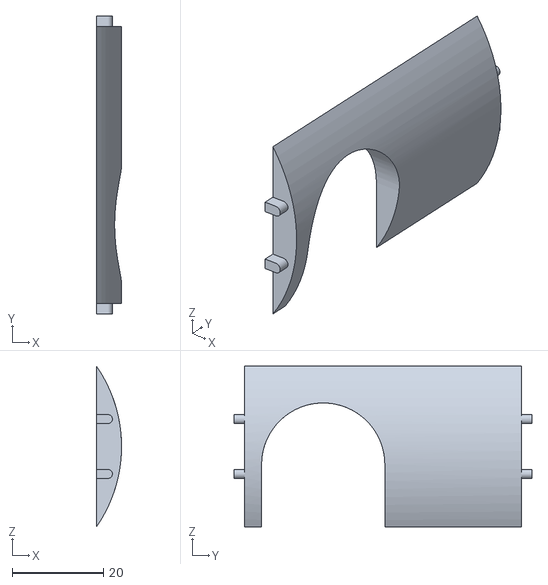
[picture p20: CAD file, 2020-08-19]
Probe/Hardware/Case/DvirkaProKam(2x, CPE).stl
5.51 x 65.2 x 35.3

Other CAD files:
Probe/Hardware/Components/MicroSD Slot/GCT/GCT_MEM20670218000A_2/MEM2067-02-180-00-A.stp
Probe/openCanSat PKII/PouzdroOCS(PETG).stl
Parachute/ParachuteRetainer.stl
Probe/Hardware/Case/PlastPKII(TPU).stl
Parachute/Kolicek(6x, CPE, co nejdetailnejsi).stl
Probe/Hardware/Components/Molex 1461680001/1461680001.stp
Probe/Hardware/Components/Voltage Regulator/LIB_LD3985M33R/LD3985M33R/3D/LD3985M33R.stl
Probe/Hardware/Components/Voltage Regulator/LIB_LD3985M33R/LD3985M33R/Allegro/sot95p280x145-5n.psm
Probe/Hardware/Components/Voltage Regulator/LIB_LD3985M33R/LD3985M33R/DEHDL/ld3985m33r/chips/chips.prt

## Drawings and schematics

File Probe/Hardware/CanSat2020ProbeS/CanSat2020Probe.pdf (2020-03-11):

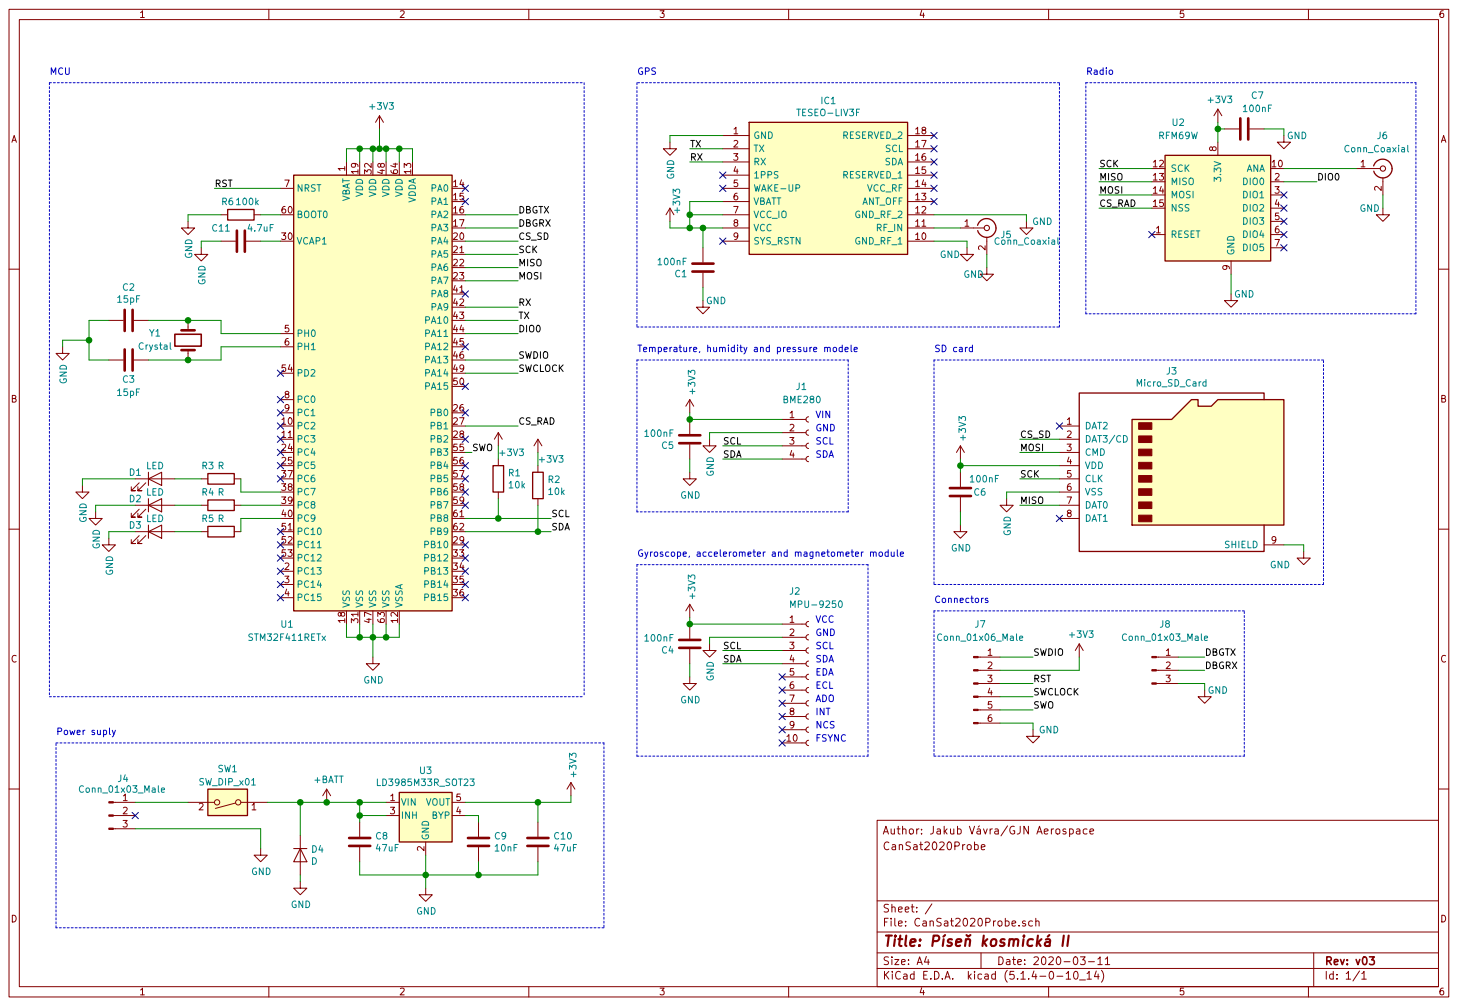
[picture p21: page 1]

1 VCAP1 30 VDD 19 VDD 32 VDD 48 VDD 64 VDDA 13 VSS 18 VSS 31 VSS 47 VSS 63 VSSA 12 U1 STM32F411RETx Y1 Crystal C2

Gyroscope, accelerometer and magnetometer module

Id: 1/1 Title: Píse kosmická II File: CanSat2020Probe.sch Sheet: / CanSat2020Probe Author: Jakub Vávra/GJN Aerospace

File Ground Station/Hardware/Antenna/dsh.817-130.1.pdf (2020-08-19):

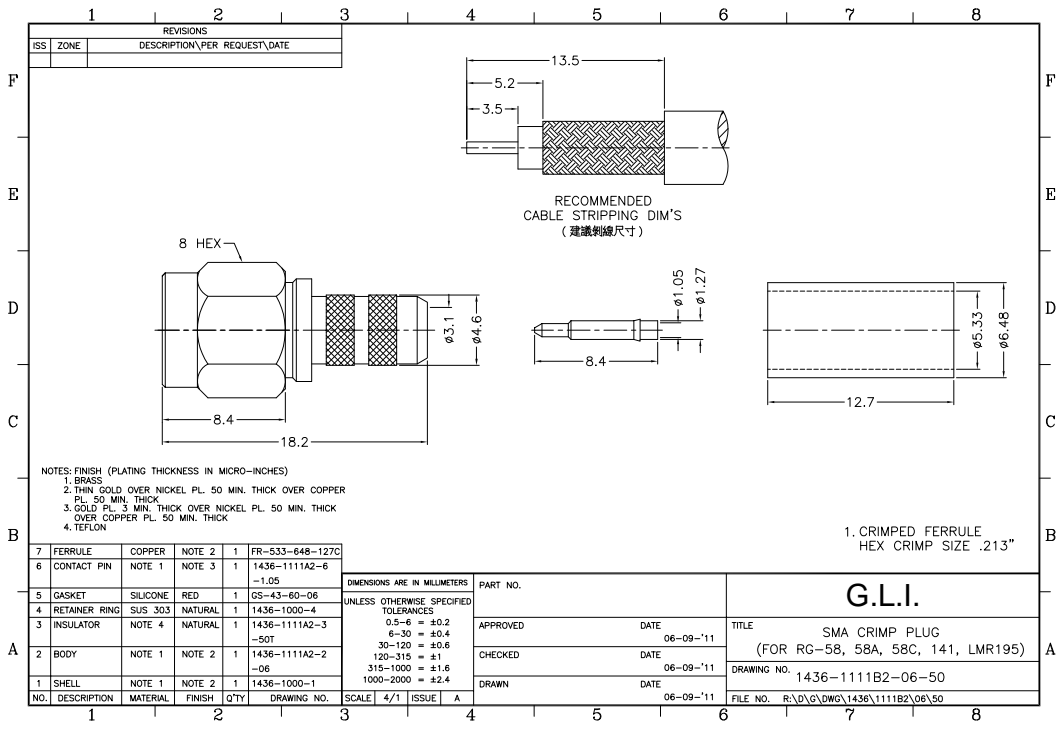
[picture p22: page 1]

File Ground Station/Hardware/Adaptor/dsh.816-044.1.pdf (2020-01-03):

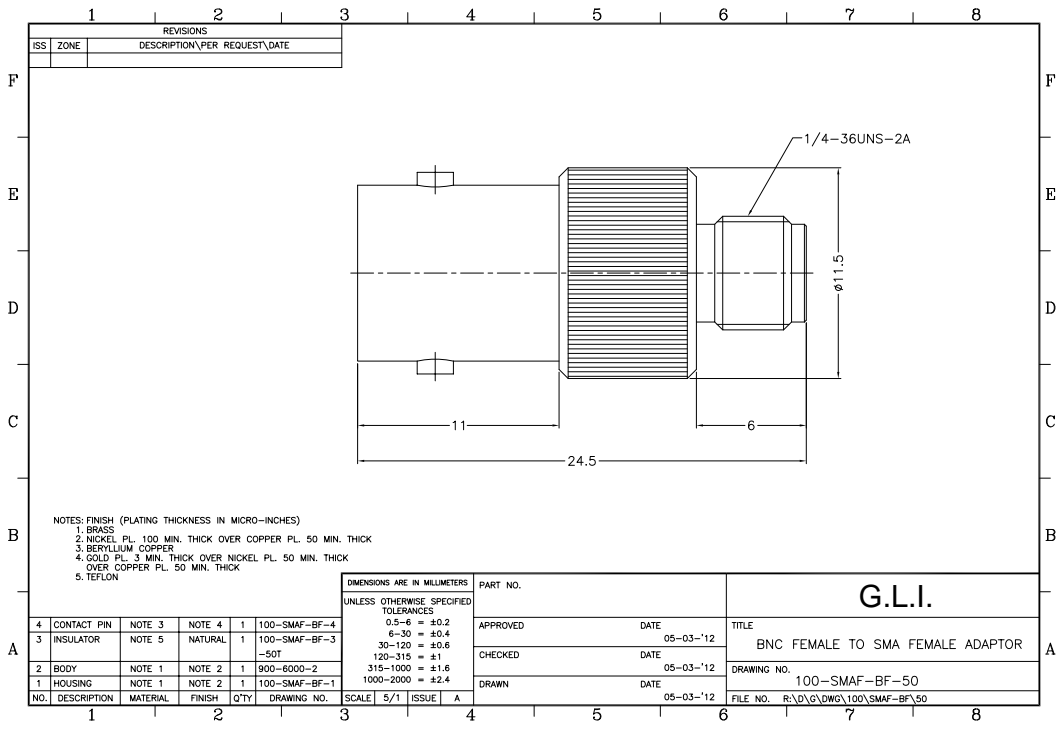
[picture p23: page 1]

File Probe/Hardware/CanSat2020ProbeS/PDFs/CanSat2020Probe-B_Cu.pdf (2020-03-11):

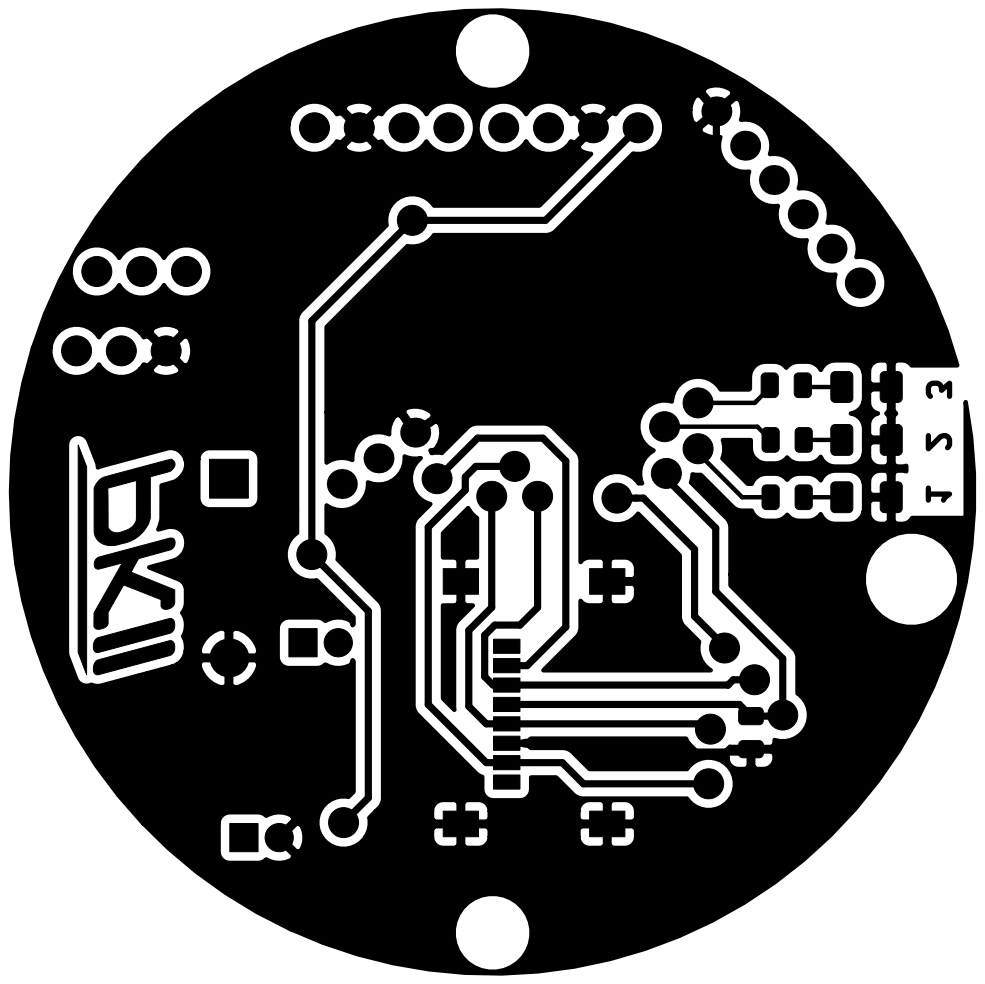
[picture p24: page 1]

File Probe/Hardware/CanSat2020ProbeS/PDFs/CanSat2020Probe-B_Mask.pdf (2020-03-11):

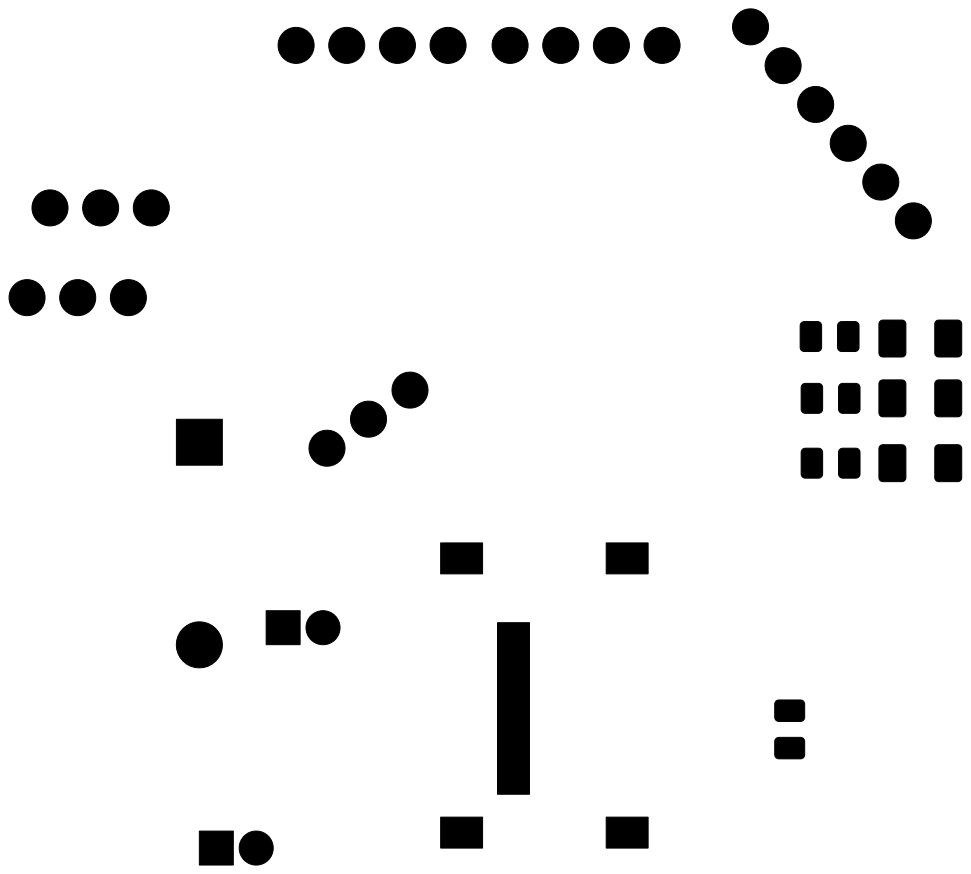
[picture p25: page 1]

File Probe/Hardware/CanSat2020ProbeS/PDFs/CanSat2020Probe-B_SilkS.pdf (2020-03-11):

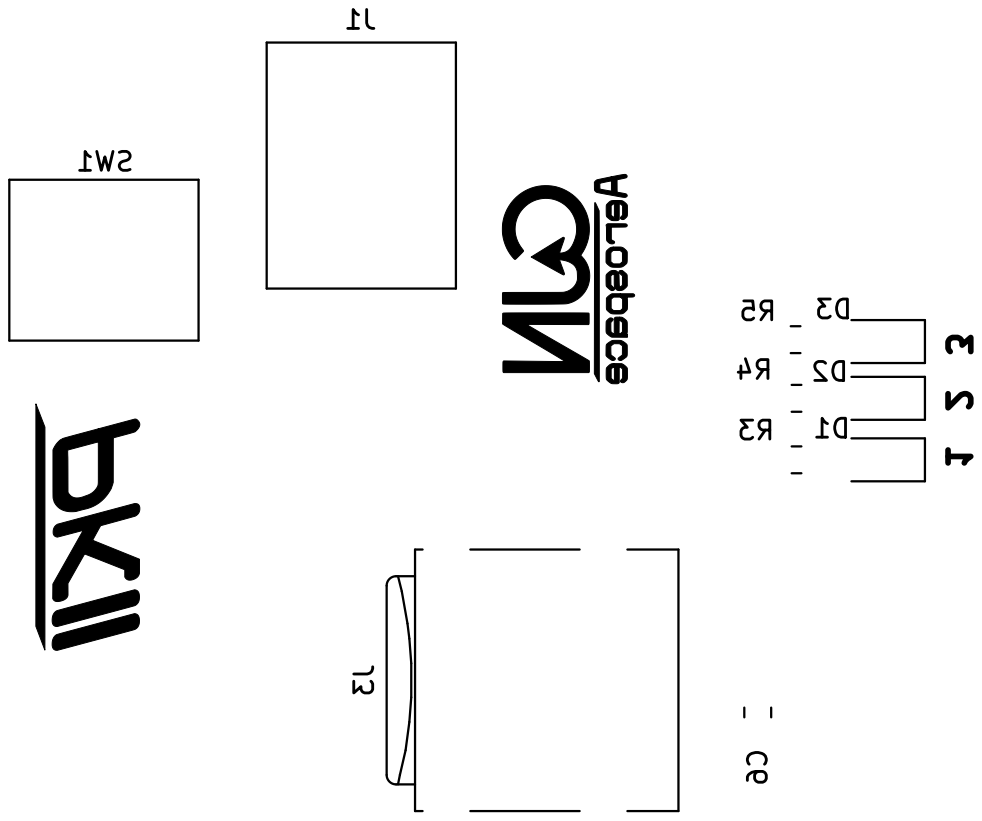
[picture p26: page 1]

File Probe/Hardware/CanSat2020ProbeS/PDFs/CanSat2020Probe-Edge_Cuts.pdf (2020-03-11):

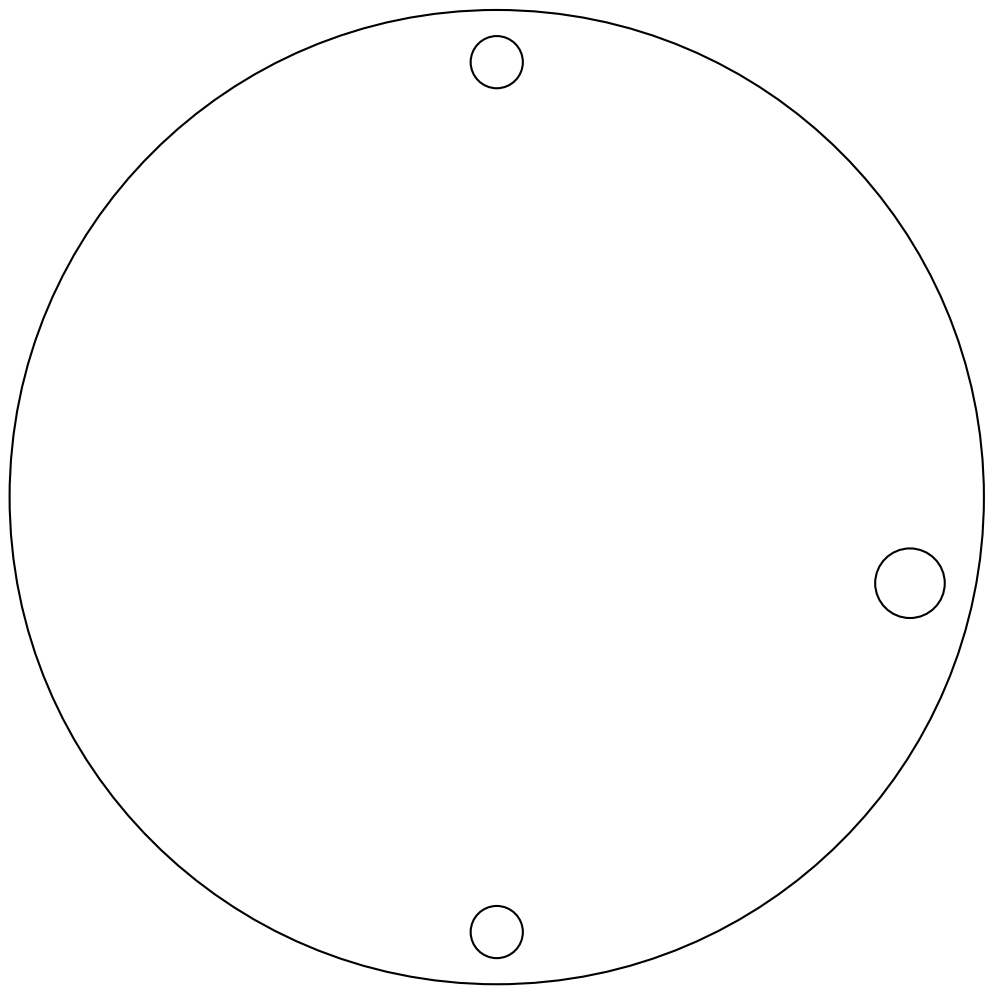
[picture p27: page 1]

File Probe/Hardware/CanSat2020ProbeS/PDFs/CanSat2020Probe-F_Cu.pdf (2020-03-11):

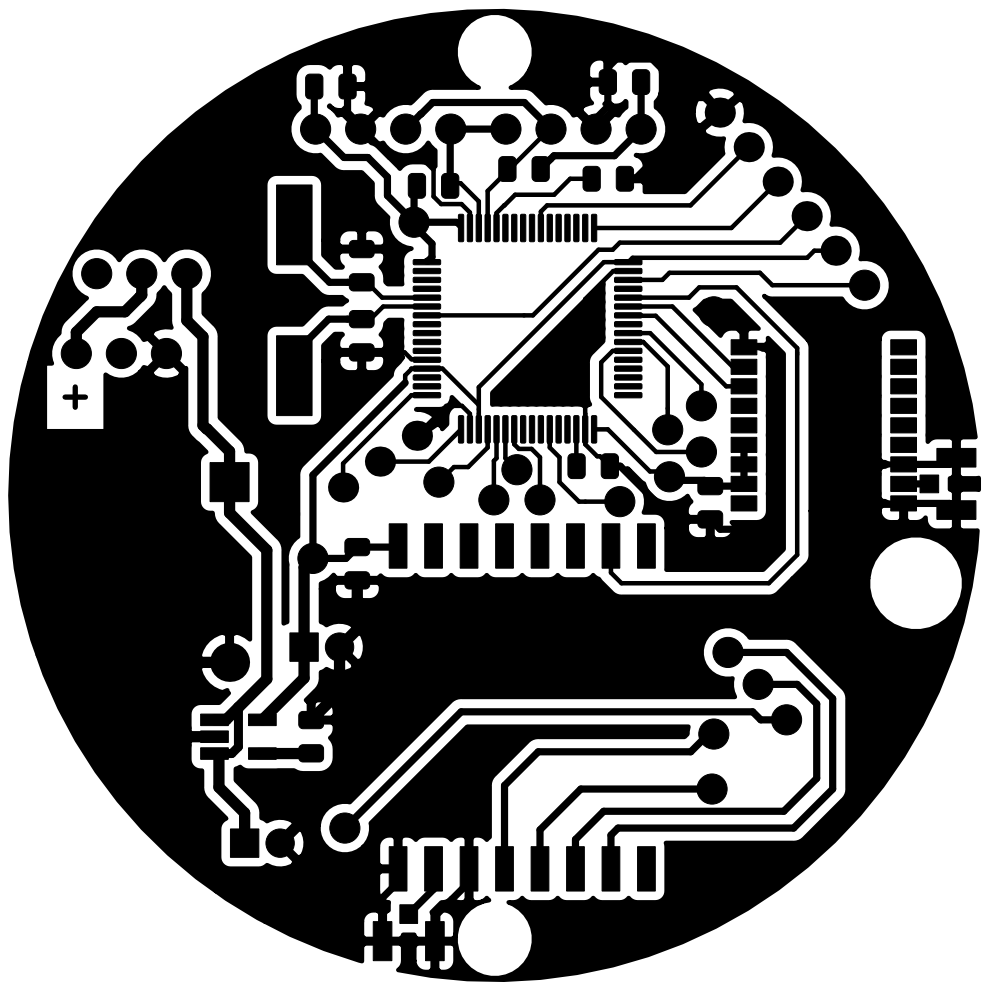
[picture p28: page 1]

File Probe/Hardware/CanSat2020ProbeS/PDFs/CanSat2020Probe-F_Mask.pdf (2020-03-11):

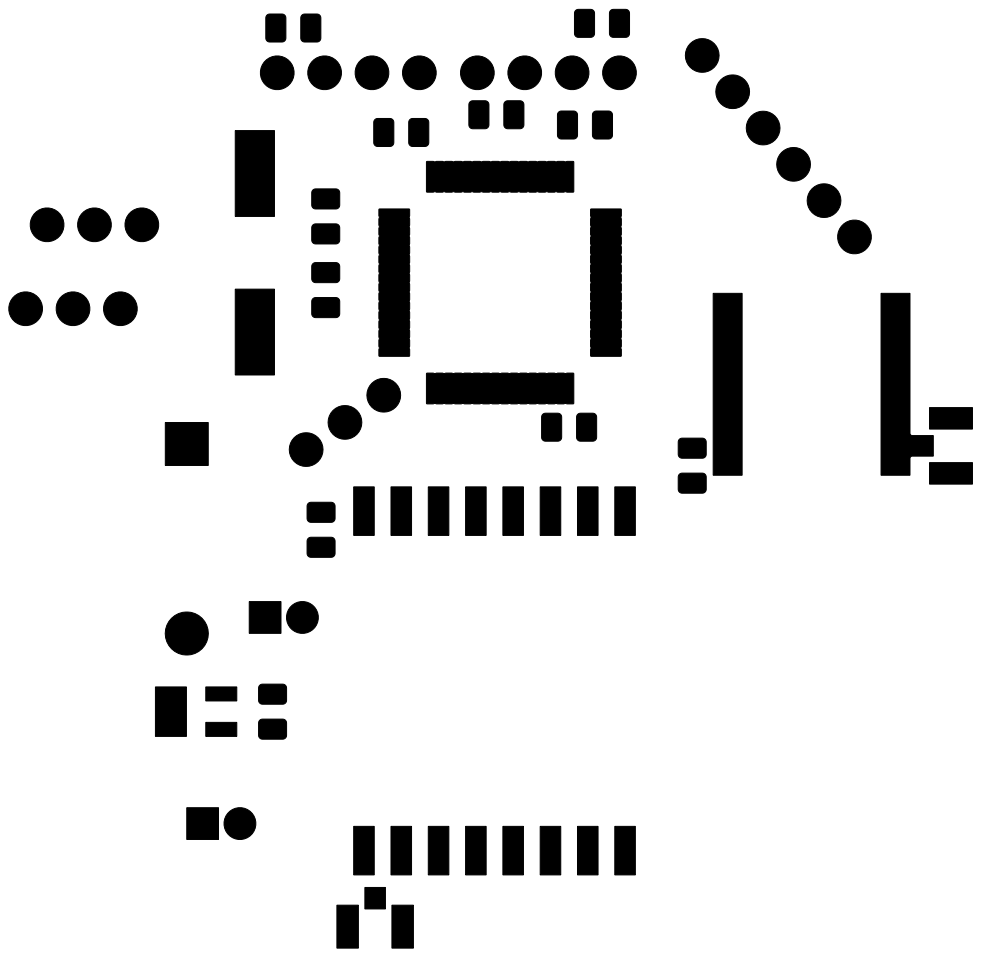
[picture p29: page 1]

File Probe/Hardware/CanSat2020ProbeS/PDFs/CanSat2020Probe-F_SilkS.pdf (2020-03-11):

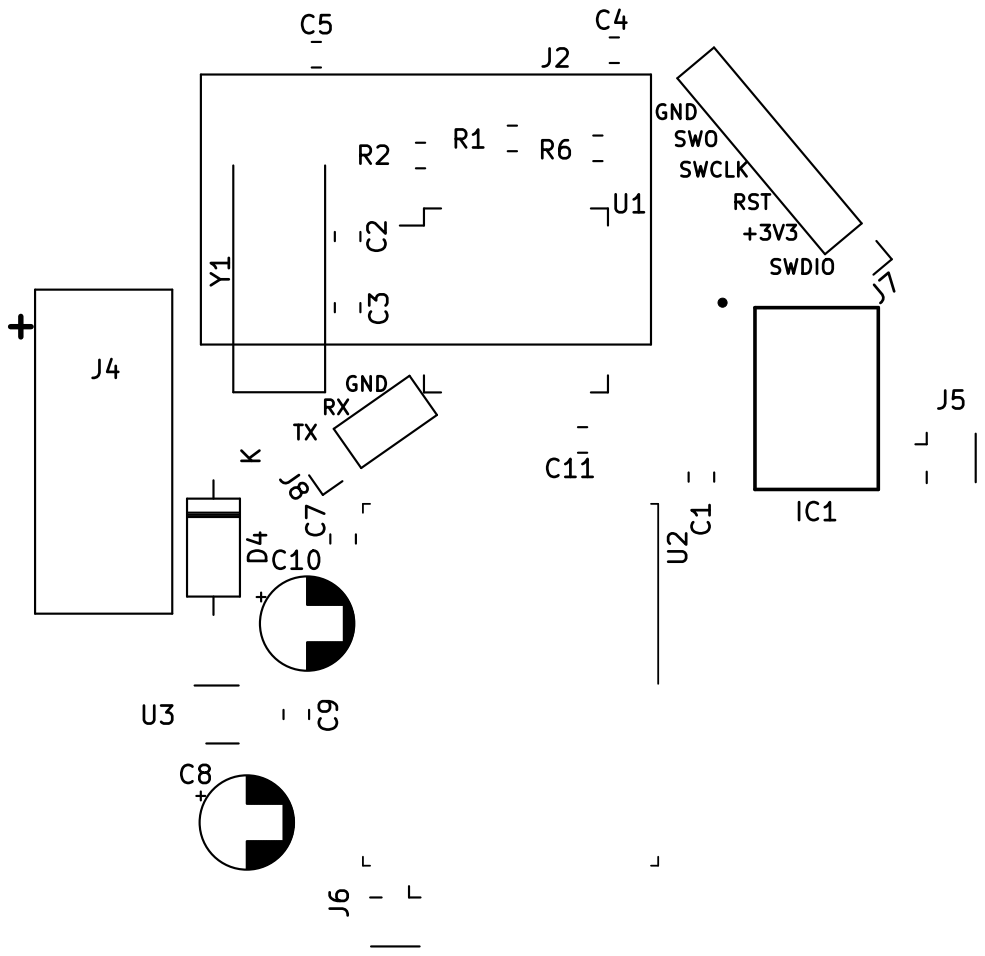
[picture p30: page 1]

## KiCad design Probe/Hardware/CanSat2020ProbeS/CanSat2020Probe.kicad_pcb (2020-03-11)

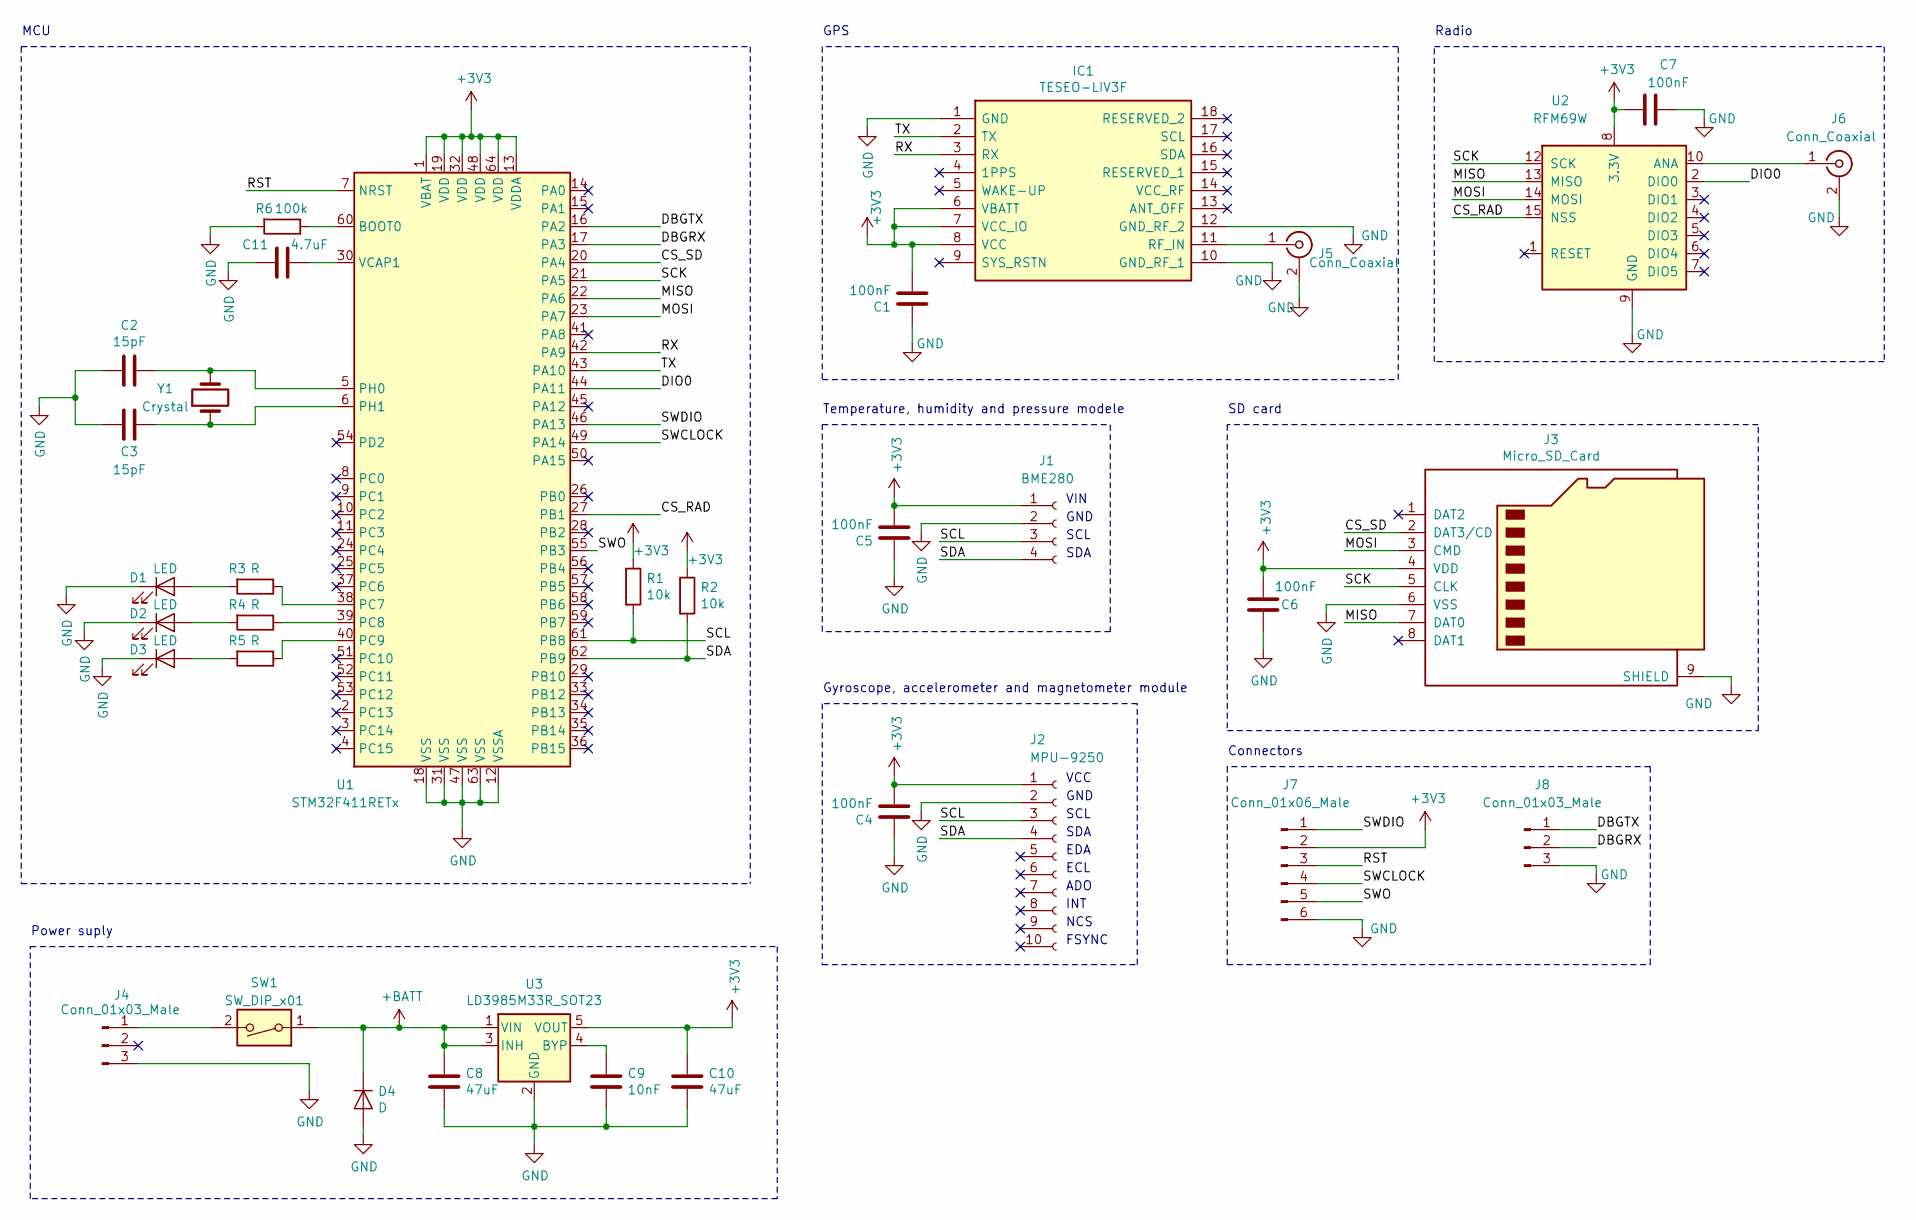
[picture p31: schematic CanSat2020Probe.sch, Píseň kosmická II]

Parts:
C1, C4, C5, C6, C7: 100nF; C_0805_2012Metric
C2, C3: 15pF; C_0805_2012Metric
C8, C10: 47uF; CP_Radial_D5.0mm_P2.00mm
C9: 10nF; C_0805_2012Metric
C11: 4.7uF; C_0805_2012Metric
D1, D2, D3: LED; LED_1206_3216Metric
D4: D; D_DO-41_SOD81_P10.16mm_Horizontal
IC1: TESEO-LIV3F; SON110P970X1010X230-18N; Manufacturer_Part_Number TESEO-LIV3F; Mouser Part Number 511-TESEO-LIV3F
J1: BME280
J2: MPU-9250; MPU-9250-4pin
J3: Micro_SD_Card; microSD_HC_Wuerth_693072010801
J4: Conn_01x03_Male; Batt_PHS_Hor_Long18mm
J5, J6: Conn_Coaxial; U.FL_Hirose_U.FL-R-SMT-1_Vertical
J7: Conn_01x06_Male; PinHeader_1x06_P2.54mm_Vertical
J8: Conn_01x03_Male; PinHeader_1x03_P2.54mm_Vertical
R1, R2: 10k; R_0805_2012Metric
R3, R4, R5: R; R_0805_2012Metric
R6: 100k; R_0805_2012Metric
SW1: SW_DIP_x01; Sw_ESP2010
U1: STM32F411RETx; LQFP-64_10x10mm_P0.5mm
U2: RFM69W; HOPERF_RFM69HW
U3: LD3985M33R_SOT23; SOT-23-5_HandSoldering
Y1: Crystal; Crystal_SMD_HC49-SD

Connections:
+3V3: C1.1, C4.1, C5.1, C6.1, C7.1, C10.1, IC1.6 (VBATT), IC1.7 (VCC_IO), IC1.8 (VCC), J1.1, J2.1, J3.4 (VDD), J7.2, R1.1, R2.1, U1.1 (VBAT), U1.13 (VDDA), U1.19 (VDD), U1.32 (VDD), U1.48 (VDD), U1.64 (VDD), U2.8 (3.3V), U3.5 (VOUT)
+BATT: C8.1, D4.1 (K), SW1.1, U3.1 (VIN), U3.3 (INH)
/CS_RAD: U1.27 (PB1), U2.15 (NSS)
/CS_SD: J3.2 (DAT3/CD), U1.20 (PA4)
/DBGRX: J8.2, U1.17 (PA3)
/DBGTX: J8.1, U1.16 (PA2)
/DIO0: U1.44 (PA11), U2.2 (DIO0)
/MISO: J3.7 (DAT0), U1.22 (PA6), U2.13 (MISO)
/MOSI: J3.3 (CMD), U1.23 (PA7), U2.14 (MOSI)
/RST: J7.3, U1.7 (NRST)
/RX: IC1.3 (RX), U1.42 (PA9)
/SCK: J3.5 (CLK), U1.21 (PA5), U2.12 (SCK)
/SCL: J1.3, J2.3, R1.2, U1.61 (PB8)
/SDA: J1.4, J2.4, R2.2, U1.62 (PB9)
/SWCLOCK: J7.4, U1.49 (PA14)
/SWDIO: J7.1, U1.46 (PA13)
/SWO: J7.5, U1.55 (PB3)
/TX: IC1.2 (TX), U1.43 (PA10)
GND: C1.2, C2.2, C3.1, C4.2, C5.2, C6.2, C7.2, C8.2, C9.2, C10.2, C11.2, D1.1 (K), D2.1 (K), D3.1 (K), D4.2 (A), IC1.1 (GND), IC1.10 (GND_RF_1), IC1.12 (GND_RF_2), J1.2, J2.2, J3.6 (VSS), J3.9 (SHIELD), J4.3, J5.2 (Ext), J6.2 (Ext), J7.6, J8.3, R6.2, U1.12 (VSSA), U1.18 (VSS), U1.31 (VSS), U1.47 (VSS), U1.63 (VSS), U2.9 (GND), U2.11 (GND), U3.2 (GND)
unnamed: C2.1, U1.5 (PH0), Y1.2
unnamed: C3.2, U1.6 (PH1), Y1.1
unnamed: C9.1, U3.4 (BYP)
unnamed: C11.1, U1.30 (VCAP1)
unnamed: D1.2 (A), R3.2
unnamed: D2.2 (A), R4.2
unnamed: D3.2 (A), R5.2
unnamed: IC1.11 (RF_IN), J5.1 (In)
unnamed: J4.1, SW1.2
unnamed: J6.1 (In), U2.10 (ANA)
unnamed: R3.1, U1.38 (PC7)
unnamed: R4.1, U1.39 (PC8)
unnamed: R5.1, U1.40 (PC9)
unnamed: R6.1, U1.60 (BOOT0)

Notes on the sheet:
VIN
GND
SCL
SDA
VCC
GND
SCL
EDA
ECL
ADO
INT
NCS
FSYNC
MCU
GPS
Radio
SD card
Temperature, humidity and pressure modele
Gyroscope, accelerometer and magnetometer module
Power suply
Connectors

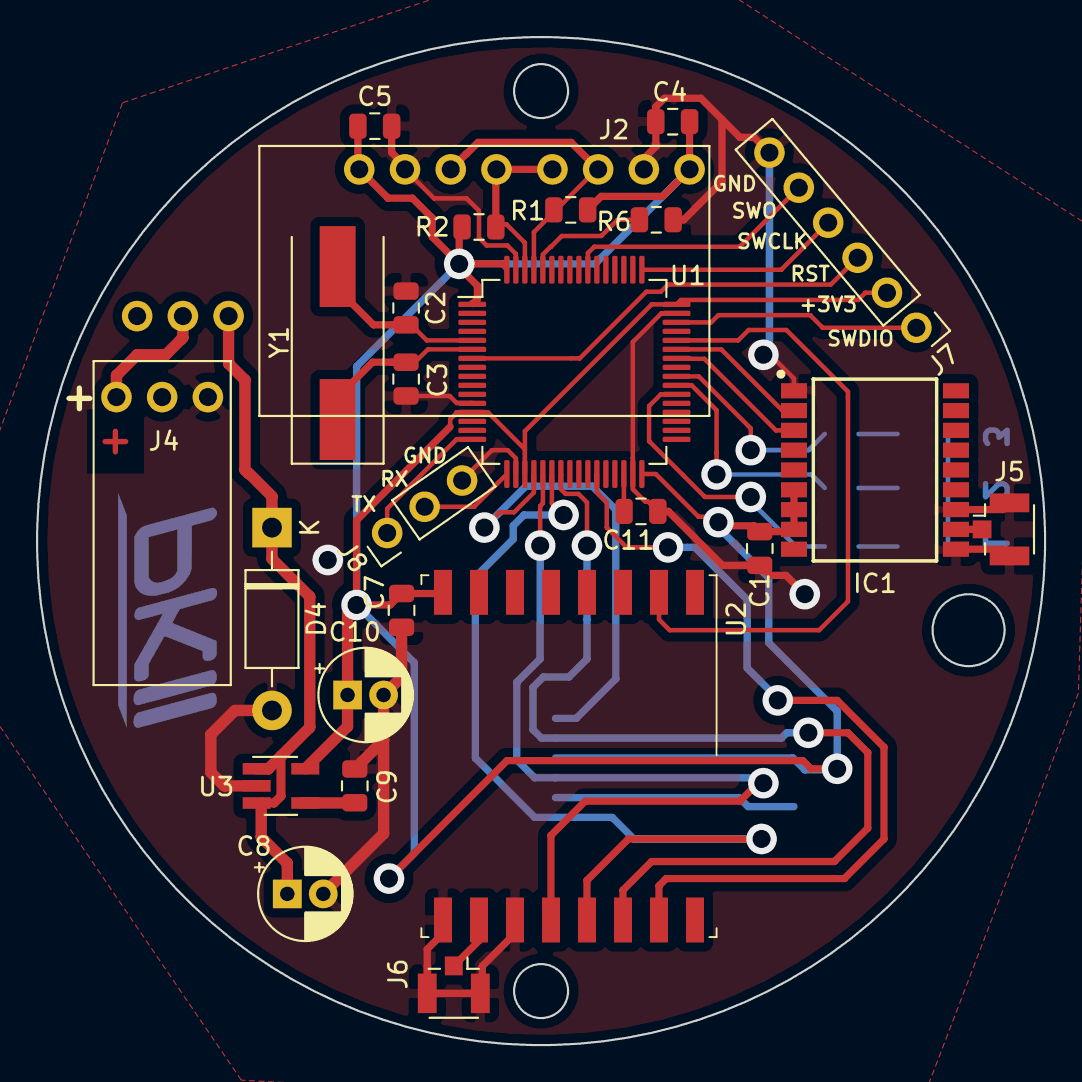
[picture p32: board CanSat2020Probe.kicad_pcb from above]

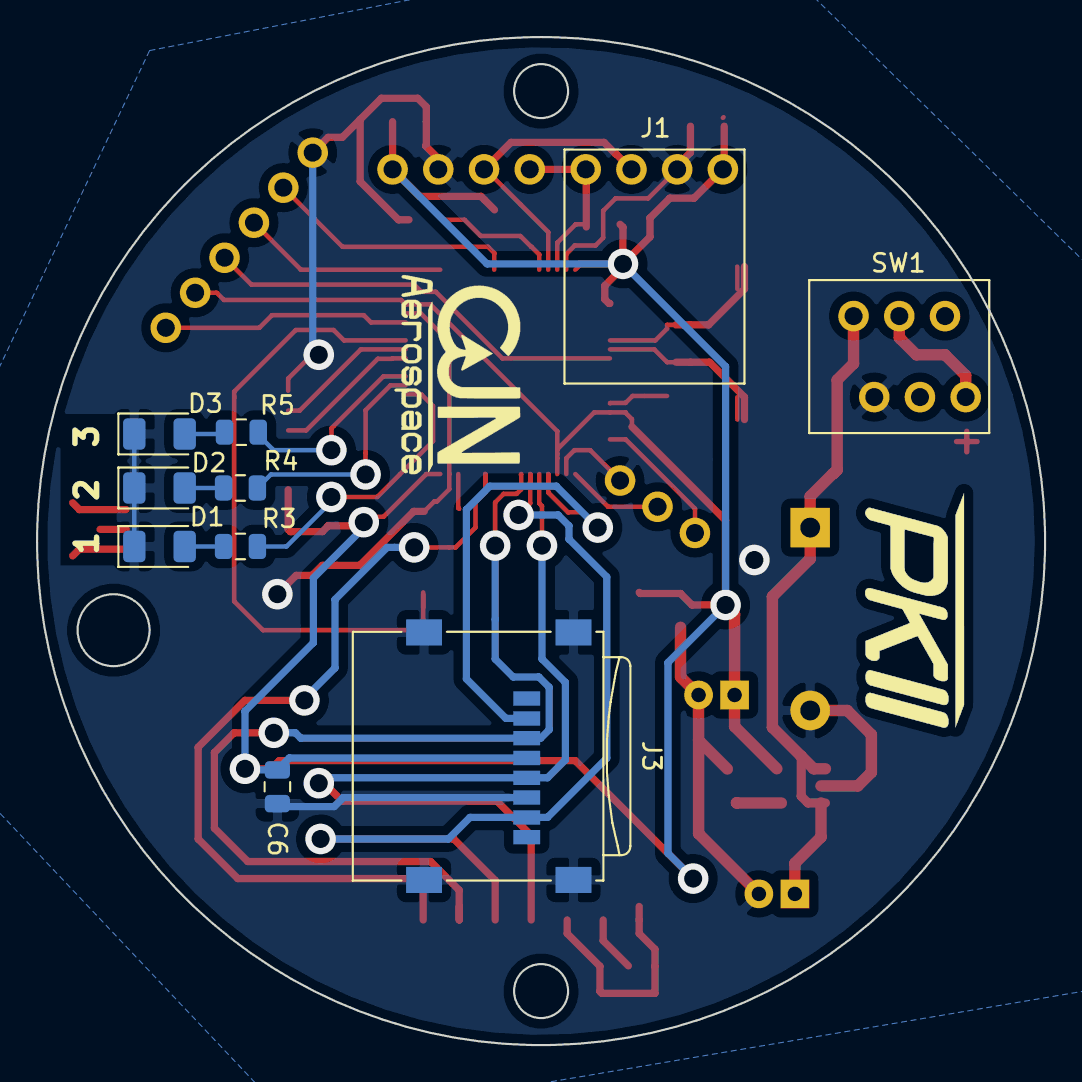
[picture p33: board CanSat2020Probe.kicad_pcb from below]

Board: 2 copper layers, 56.0 x 56.0 mm, 35 parts (10 on the bottom side), 33 nets.

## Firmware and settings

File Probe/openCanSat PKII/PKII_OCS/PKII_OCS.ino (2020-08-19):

#include "Arduino.h"

#include <Adafruit_BME280.h>  // include Adafruit BME280 library
#include <Adafruit_INA219.h>  // include INA219
#include <SD.h> 				 // include Arduino SD library
#include "SparkFun_Ublox_Arduino_Library.h" //include SparkFun Ublox Arduino Library
#include <RFM69.h>			 // include RFM69 library
#include <SPI.h>
#include <Wire.h>

// Local
#define PC_BAUDRATE 57600
#define MS_DELAY 250  // Number of milliseconds between data sending and LED signalization
#define LED_DELAY 0
#define Serial SerialUSB

// RFM69
#define NETWORKID 0  		   // Must be the same for all nodes (0 to 255)
#define MYNODEID 1   		   // My node ID (0 to 255)
#define TONODEID 2   		   // Destination node ID (0 to 254, 255 = broadcast)
#define FREQUENCY RF69_433MHZ   // Frequency set up
#define FREQUENCYSPECIFIC 433800000  // Should be value in Hz, now 433 Mhz will be set
#define CHIP_SELECT_PIN 43 //radio chip select
#define INTERUP_PIN 9 //radio interrupt
#define ENCRYPTKEY    "sampleEncryptKey"

// BME280 SETTING
#define BME280_ADDRESS_OPEN_CANSAT1 0x77
#define BME280_ADDRESS_OPEN_CANSAT2 0x76
#define SEALEVELPRESSURE_HPA 1013.25

//calibrate BME280
#define calibPress 0 //Pressure difference between reality and BME280 sensor value
#define calibTempA 1 //1 is default, A value for y = a*x+b where x is the initial temperature value
#define calibTempB 0 //0 is default, B value for y = a*x+b where x is the initial temperature value
#define calibHumA 1 //1 is default, A value for y = a*x+b where x is the initial humidity value
#define calibHumB 0 //0 is default, B value for y = a*x+b where x is the initial humidity value

//GPS time adjustment
#define summerTime 1
#define timeZone 1

// SD card
#define sd_cs_pin 35 // set SD's chip select pin (according to the circuit)

//create GPS object
SFE_UBLOX_GPS myGPS;

// create object 'rf69' from the library, which will
RFM69 radio(CHIP_SELECT_PIN, INTERUP_PIN, true);

// define our own struct data type with variables; used to send data
typedef struct
{
  int16_t messageId;
  uint16_t year;
  uint8_t month;
  uint8_t day;
  uint8_t hour;
  uint8_t minute;
  uint8_t sec;
  long latitude;
  long longitude;
  long altitudeGPS;
  byte SIV;
  float temperature;
  float pressure;
  float altitude;
  float humidity;
  float voltage_shunt;
  float voltage_bus;
  float current_mA;
  float voltage_load;
  int16_t rssi;
  float temperature_wrong;
  float pressure_wrong;
  float altitude_wrong;
  float humidity_wrong;
} messageOut;

messageOut data; //create the struct variable

// create object 'bme' from the library, which will
Adafruit_BME280 bme1;
Adafruit_BME280 bme2;

// create object 'ina219' from the library with address 0x40
Adafruit_INA219 ina219(0x40);

// SD card file
File file;

// LEDS
#define D13_led_pin 42 	// D13 LED
#define M_led_pin 36 	// MLED

// Local variables
int idCounter = 1;
bool isBmeOk = true;
bool isSdOk = true;
bool isRadioOk = true;
long lastTime = 0; //Simple local timer. Limits amount if I2C traffic to Ublox module.

void setup()
{ 
  Serial.begin(PC_BAUDRATE);

  //uncomment for use with computer
  // while(!Serial);

  Serial.println("PKII OCS");

  Serial.print("Node ");
  Serial.print(MYNODEID,DEC);
  Serial.println(" ready");
  
  // begin communication with the BME280 on the previously specified address
  if (!bme1.begin(BME280_ADDRESS_OPEN_CANSAT1))
  {
	  isBmeOk = false;
	  Serial.println("Could not find a valid first BME280 sensor");
	  return;
  }

  if (!bme2.begin(BME280_ADDRESS_OPEN_CANSAT2))
  {
    isBmeOk = false;
    Serial.println("Could not find a valid second BME280 sensor");
    return;
  }

  // begin communication with the INA219
  ina219.begin();

  if (!SD.begin(sd_cs_pin))
  {
    Serial.println("SD card initialization failed");
    return;
   }

  if(!radio.initialize(FREQUENCY, MYNODEID, NETWORKID))
  {
	  isRadioOk = false;
	  Serial.println("RFM69HW initialization failed");
  }
  else {
    radio.setFrequency(FREQUENCYSPECIFIC);
	  radio.setHighPower(true); // Always use this for RFM69HW
    //radio.encrypt(ENCRYPTKEY);
  }

  //LEDs
  pinMode(D13_led_pin, OUTPUT);
  pinMode(M_led_pin, OUTPUT);

  Wire.begin();

  if (myGPS.begin() == false) //Connect to the Ublox module using Wire port
  {
    Serial.println(F("Ublox GPS not detected at default I2C address"));
    while (1);
  }

  myGPS.setI2COutput(COM_TYPE_UBX); //Set the I2C port to output UBX only (turn off NMEA noise)
  myGPS.saveConfiguration();        //Save the current settings to flash and BBR

}

void loop()
{
  //LED
  digitalWrite(D13_led_pin, HIGH);
  digitalWrite(M_led_pin, HIGH);
  
  data.messageId = idCounter;

  Serial.println("MessageId = " + static_cast<String>(data.messageId));

  //BME280
  data.temperature = 0;
  data.pressure = 0;
  data.altitude = 0;
  data.humidity = 0;

  data.temperature_wrong = 0;
  data.pressure_wrong = 0;
  data.altitude_wrong = 0;
  data.humidity_wrong = 0;

  if(isBmeOk)
  {
	  data.temperature += bme2.readTemperature();
	  data.pressure += bme2.readPressure() / 100.0F;
	  data.altitude += bme2.readAltitude(SEALEVELPRESSURE_HPA);
	  data.humidity = bme2.readHumidity();
    
    data.temperature_wrong = bme1.readTemperature();
    data.pressure_wrong = bme1.readPressure() / 100.0F;
    data.altitude_wrong = bme1.readAltitude(SEALEVELPRESSURE_HPA);
    data.humidity_wrong = bme1.readHumidity();
  }

  Serial.println("Temperature2 = " + static_cast<String>(data.temperature) + " *C");
  Serial.println("Temperature1 = " + static_cast<String>(data.temperature_wrong) + " *C");
  Serial.println("Pressure2 = " + static_cast<String>(data.pressure) + " Pa");
  Serial.println("Pressure1 = " + static_cast<String>(data.pressure_wrong) + " Pa");
  Serial.println("Approx altitude2 = " + static_cast<String>(data.altitude) + " m");
  Serial.println("Approx altitude1 = " + static_cast<String>(data.altitude_wrong) + " m");
  Serial.println("Humidity2 = " + static_cast<String>(data.humidity) + " %");
  Serial.println("Humidity1 = " + static_cast<String>(data.humidity_wrong) + " %");

  //INA219
  data.voltage_shunt = ina219.getShuntVoltage_mV();
  data.voltage_bus = ina219.getBusVoltage_V();
  data.current_mA = ina219.getCurrent_mA();
  data.voltage_load = data.voltage_bus + (data.voltage_shunt / 1000);

  Serial.println("Shunt Voltage: " + static_cast<String>(data.voltage_shunt) + " mV");
  Serial.println("Bus Voltage: " + static_cast<String>(data.voltage_bus) + " V");
  Serial.println("Current: " + static_cast<String>(data.current_mA) + " mA");
  Serial.println("Load Voltage: " + static_cast<String>(data.voltage_load) + " V");

  //GPS
  data.year = 0;
  data.month = 0;
  data.day = 0;
  data.hour = 0;
  data.minute = 0;
  data.sec = 0;
  data.latitude = 0;
  data.longitude = 0;
  data.altitudeGPS = 0;
  data.SIV = 0;

  if (millis() - lastTime > 1000)
  {
    lastTime = millis(); //Update the timer

    data.latitude = myGPS.getLatitude();
    data.longitude = myGPS.getLongitude();
    data.altitudeGPS = myGPS.getAltitude();
    data.year = myGPS.getYear();
    data.month = myGPS.getMonth();
    data.day = myGPS.getDay();
    data.hour = myGPS.getHour();
    data.minute = myGPS.getMinute();
    data.sec = myGPS.getSecond();
    data.SIV = myGPS.getSIV();   

    Serial.print("Lat: " + static_cast<String>(data.latitude));
    Serial.print(" Long: " + static_cast<String>(data.longitude));
    Serial.print(" (degrees * 10^-7)");
    Serial.print(" Alt: " + static_cast<String>(data.altitudeGPS));
    Serial.print(" (mm)");
    Serial.print(" SIV: " + static_cast<String>(data.SIV));

    Serial.println();
    Serial.print(data.year);
    Serial.print("-");
    Serial.print(data.month);
    Serial.print("-");
    Serial.print(data.day);
    Serial.print(" ");
    Serial.print(data.hour + summerTime + timeZone);
    Serial.print(":");
    Serial.print(data.minute);
    Serial.print(":");
    Serial.print(data.sec);

    Serial.println();
  }
  
  //RFM69HW
  data.rssi = 0;

  if(isRadioOk)
  {
	  data.rssi = radio.RSSI;
	  Serial.println("Signal = " + static_cast<String>(radio.RSSI));

	  radio.send(TONODEID, (const void*)&data, sizeof(data));
  }

  //SD
  file = SD.open("data.csv", FILE_WRITE);
  
  if(file)
  {
    file.print(";PKII_OCS;" + String(data.messageId));
    file.print(";" + String(calibTempA * data.temperature + calibTempB));
    file.print(";" + String(data.pressure + calibPress));
    file.print(";" + String(calibHumA * data.humidity + calibHumB));
    file.print(";" + String(data.altitude));
    file.print(";" + String(data.voltage_shunt));
    file.print(";" + String(data.voltage_bus));
    file.print(";" + String(data.current_mA));
    file.print(";" + String(data.voltage_load));
    file.print(";" + String(data.rssi));
    file.print(";" + String(data.latitude));
    file.print(";" + String(data.longitude));
    file.print(";" + String(data.latitude) + " N");
    file.print(" " + String(data.longitude) + " E");
    file.print(";" + String(data.year));
    file.print(";" + String(data.month));
    file.print(";" + String(data.day));
    file.print(";" + String(data.hour + summerTime + timeZone) + ":" + String(data.minute) + ":" + String(data.sec));
    file.print(";" + String(data.hour + summerTime + timeZone));
    file.print(";" + String(data.minute));
    file.print(";" + String(data.sec));
    file.print(";" + String(data.SIV));
    file.print(";" + String(data.altitudeGPS));
    file.print(";" + String(data.temperature_wrong));
    file.print(";" + String(data.pressure_wrong));
    file.print(";" + String(data.humidity_wrong));
    file.print(";" + String(data.altitude_wrong));
     
    file.println();
    
    file.close();
  }
  else {
    Serial.println("Error opening data.csv");
  }

  Serial.println();

  idCounter ++;

  //LED
  digitalWrite(D13_led_pin, LOW);
  digitalWrite(M_led_pin, LOW);

  delay(MS_DELAY);
}

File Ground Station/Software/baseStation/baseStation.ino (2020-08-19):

#include <OcsStorage.h>
#include <RFM69.h>
#include <Ucglib.h>
#include "Adafruit_BME280.h"
#include <SD.h>
#include <SPI.h>

#ifndef UCG_INTERRUPT_SAFE
#define UCG_INTERRUPT_SAFE
#endif

uint8_t screenNum = 1;

#define Serial SerialUSB

// LOCAL
#define PC_BAUDRATE 57600

// BUTTONS
#define BUTTON_1 5
#define BUTTON_2 4
#define BUTTON_3 3

// RFM69
#define NETWORKID 0   // Must be the same for all nodes (0 to 255)
#define MYNODEID 2   // My node ID (0 to 255)
#define FREQUENCY RF69_433MHZ
#define FREQUENCYSPECIFIC 433800000  // Should be value in Hz, now 433 Mhz will be set
#define chip_select_pin 43
#define interupt_pin 9
#define ENCRYPTKEY    "sampleEncryptKey"

// BME280
#define BME280_ADDRESS_OPEN_CANSAT 0x76   // Set BME's address (according to the circuit)
#define SEALEVELPRESSURE_HPA (1013.25)  // Set sea level pressure value(see: https://en.wikipedia.org/wiki/Atmospheric_pressure)

int ms_delay = 0;

#define calibPress 0 //Pressure difference between reality and BME280 sensor value on probe
#define calibTempA (1) //1 is default, A value for y = a*x+b where x is the initial temperature value
#define calibTempB (0) //0 is default, B value for y = a*x+b where x is the initial temperature value
#define calibHumA (1) //1 is default, A value for y = a*x+b where x is the initial humidity value
#define calibHumB (0) //0 is default, B value for y = a*x+b where x is the initial humidity value

//GPS time adjustment
#define summerTime 1
#define timeZone 1

#define sd_cs_pin 35

bool isRadioOk = true;

// create object 'rf69' from the library, which will
RFM69 radio(chip_select_pin, interupt_pin, true);

//Display
Ucglib_ST7735_18x128x160_HWSPI ucg(6, 7, -1);
OcsGraphics ocsDesign(ucg);
OcsStorage ocsData(ocsDesign);

OcsStorage::message income;

typedef struct
{
  int16_t messageId;
  uint16_t year;
  uint8_t month;
  uint8_t day;
  uint8_t hour;
  uint8_t minute;
  uint8_t sec;
  long latitude;
  long longitude;
  long altitudeGPS;
  byte SIV;
  float temperature;
  float pressure;
  float altitude;
  float humidity;
  float voltage_shunt;
  float voltage_bus;
  float current_mA;
  float voltage_load;
  int16_t rssi;
  float temperature_wrong;
  float pressure_wrong;
  float altitude_wrong;
  float humidity_wrong;
} message;

message data;

// Create object 'bme' from the library, which will
Adafruit_BME280 bme;

//SD
File file;

// Empty variables for measured values for BME280
float temperature_bme280 = 0;
float pressure_bme280 = 0;
float altitude_bme280 = 0;
float humidity_bme280 = 0;

void setup() 
{
  Serial.begin(PC_BAUDRATE);
  
  // Space behind font is transparent
  ucg.begin(UCG_FONT_MODE_TRANSPARENT);

  // Clear the screen and reset the clip range to maximum
  ucg.clearScreen();

  ocsDesign.drawBackground();
  ocsDesign.drawHomescreen();

  // Buttons
  pinMode(BUTTON_1, INPUT);
  pinMode(BUTTON_2, INPUT);
  pinMode(BUTTON_3, INPUT);

  // RFM69
  Serial.print(";baseStation ");
  Serial.print(MYNODEID,DEC);
  Serial.println(" is ready");

  if(!radio.initialize(FREQUENCY, MYNODEID, NETWORKID))
  {
	  isRadioOk = false;
	  Serial.println(";RFM69HW initialization failed!");
  }
  else {
    radio.setFrequency(FREQUENCYSPECIFIC);
	  radio.setHighPower(true); // Always use this for RFM69HW
    //radio.encrypt(ENCRYPTKEY);
  }

  // BME280
  if (!bme.begin(BME280_ADDRESS_OPEN_CANSAT))
  {
     Serial.println(";Could not find a valid BME280 sensor");
     return;
  }

  // SD
  if (!SD.begin(sd_cs_pin))
  {
    Serial.println(";SD initialisation failed");
    return;
  }

  Serial.println(";PKII;MessageID;Teplota;Tlak;Vlhkost;Výška(BME280);U-Shunt;U-Bus;Proud;U-Load;RSSI;Zem. šířka(Lat.);Zem.délka(Lon.);Rok;Měsíc;Den;Čas;Hodiny;Minuty;Sekundy;SIV;Výška(GPS);TeplotaW;TlakW;VlhkostW;VýškaW(BME280);Teplota Stanice;Tlak Stanice;Vlhkost Stanice;Výška Stanice(BME280)");
  
}

void loop()
{
  int button1 = digitalRead(BUTTON_1);
  int button2 = digitalRead(BUTTON_2);
  int button3 = digitalRead(BUTTON_3);

  if(button1 == LOW)
  {
	if(screenNum == 1)
	{
	 	screenNum = 0;
	 	ocsDesign.drawLeftScreen();
	 	delay(300);
	 	Serial.println(";Button 1 ");
	}
	else if(screenNum == 2)
	{
		screenNum = 1;
	 	ocsDesign.drawHomescreen();
	 	delay(300);
	 	Serial.println(";Button 1 ");
	}
  }
  else if(button2 == LOW)
  {
	if(screenNum != 1)
	{
	 	screenNum = 1;
	 	ocsDesign.drawHomescreen();
	 	delay(300);
	 	Serial.println(";Button 2 ");
	}
  }
  else if(button3 == LOW)
  {
	if(screenNum == 1)
	{
		screenNum = 2;
  	 	ocsDesign.drawRightScreen();
	 	delay(300);
  	 	Serial.println(";Button 3 ");
	}
	else if(screenNum == 0)
	{
		screenNum = 1;
	 	ocsDesign.drawHomescreen();
	 	delay(300);
	 	Serial.println(";Button 3 ");
	}
  }  

  // Read values from BME280 into the variables
  temperature_bme280 = bme.readTemperature();
  pressure_bme280 = bme.readPressure() / 100.0F;
  altitude_bme280 = bme.readAltitude(SEALEVELPRESSURE_HPA);
  humidity_bme280 = bme.readHumidity();

  if (radio.receiveDone())
  {
    data = *(message*)radio.DATA;

    Serial.print(";PKII_OCS;" + String(data.messageId));
    Serial.print(";" + String(calibTempA * data.temperature + calibTempB));
    Serial.print(";" + String(data.pressure + calibPress));
    Serial.print(";" + String(calibHumA * data.humidity + calibHumB));
    Serial.print(";" + String(data.altitude));
    Serial.print(";" + String(data.voltage_shunt));
    Serial.print(";" + String(data.voltage_bus));
    Serial.print(";" + String(data.current_mA));
    Serial.print(";" + String(data.voltage_load));
    Serial.print(";" + String(data.rssi));
    Serial.print(";" + String(data.latitude));
    Serial.print(";" + String(data.longitude));
    Serial.print(";" + String(data.latitude) + " N");
    Serial.print(" " + String(data.longitude) + " E");
    Serial.print(";" + String(data.year));
    Serial.print(";" + String(data.month));
    Serial.print(";" + String(data.day));
    Serial.print(";" + String(data.hour + summerTime + timeZone) + ":" + String(data.minute) + ":" + String(data.sec));
    Serial.print(";" + String(data.hour + summerTime + timeZone));
    Serial.print(";" + String(data.minute));
    Serial.print(";" + String(data.sec));
    Serial.print(";" + String(data.SIV));
    Serial.print(";" + String(data.altitudeGPS));
    Serial.print(";" + String(data.temperature_wrong));
    Serial.print(";" + String(data.pressure_wrong));
    Serial.print(";" + String(data.humidity_wrong));
    Serial.print(";" + String(data.altitude_wrong));
     
    // BaseStation data
    Serial.print(";" + (String) temperature_bme280);  
    Serial.print(";" + (String) pressure_bme280);
    Serial.print(";" + (String) humidity_bme280);
    Serial.print(";" + (String) altitude_bme280);
    
    Serial.println();

    file = SD.open("data.csv", FILE_WRITE);
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

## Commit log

2019-10-28 přidání KiCad souboru
    [CanSat2020Probe.kicad_pcb, CanSat2020Probe.sch]
2019-12-23 Add components descriptions
    [1461680001.stp, Connectors.SchDoc, EDI2CAP.CFG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]
2020-01-01 addition of new components
    [CanSat2020Probe.sch, ShopCart(CZK).csv]
2020-01-03 new parts and reorganisation
    [02i31889.drl, 02i31889.gbl, 02i31889.gbo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]
2020-01-12 minor changes
    [02i31889.drl, 02i31889.gbl, 02i31889.gbo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]
2020-01-25 small changes
    [CanSat2020Probe.kicad_pcb, CanSat2020Probe.sch, ShopCart(CZK).csv]
2020-02-29 minor improvements
    [CanSat2020Probe.kicad_pcb, CanSat2020Probe.sch, RFM69HW-868S2--3DModel-STEP-1.STEP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]
